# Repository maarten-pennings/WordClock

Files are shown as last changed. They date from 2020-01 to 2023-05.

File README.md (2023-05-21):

# WordClock
A clock that tells time in plain text. In Dutch, e.g. "TIEN OVER HALF TWAALF".

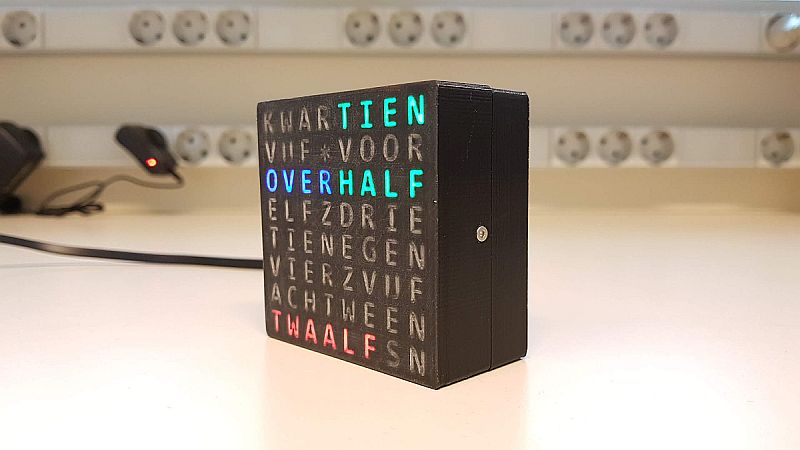
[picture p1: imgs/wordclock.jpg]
WordClock


Commercial [products](https://qlocktwo.com/) exist, but I'm making my own.

Here is a demo [video](https://youtu.be/8YMuuo80cz0) of all animations,
or look at just
[none](https://youtu.be/OCgUQ6qWnN4),
[wipe](https://youtu.be/U9yd8xaslh4),
[dots](https://youtu.be/AXKME2LGA_A),
[pulse](https://youtu.be/F0VIralrmUM), or
[mist](https://youtu.be/u285F07go_c).

There is a [video](https://youtu.be/0UkmPO7tGsg) looking at the mechanics (casing) of the WordClock,
and a [video](https://youtu.be/4AUioVwlsqg) comparing it to a DCF77 clock.

I also made a [white](https://youtu.be/0g2qCgmOJZo) version.

This is the [playlist](https://www.youtube.com/playlist?list=PLrlJSwck1Q0i3ywVSwM-FqwnLM_yhguJa) of all WordClock videos.

## Table of contents

 - [1. Introduction](#1-Introduction) - What is this project about
 - [2. Model 1](#2-Model-1) - My first experiment
 - [3. Model 2](#3-Model-2) - Improved lettering
 - [4. 3D printing](#4-3D-printing) - 3D printed lettering
 - [5. NeoPixel power](#5-NeoPixel-power) - How much power is needed for NeoPixels
 - [6. Model 3](#6-Model-3) - Using the 3D printed lettering
 - [7. Keeping time](#7-Keeping-time) - How to keep time with NTP
 - [8. Timing](#8-Timing) - Disable interrupts disables time keeping
 - [9. Power architecture](#9-Power-architecture) - How to provide power to the NeoPixels
 - [10. Modding the board](#10-Modding-the-board) - Selecting an ESP8266 board
 - [11. Model 4](#11-Model-4) - Assembling the electronics and 3D printed case
 - [12. Model 5](#12-Model-5) - Adding the time keeping software
 - [13. Model 6](#13-Model-6) - End-user application "WordClockFull"
 - [14. User manual](#14-User-manual) - The user manual of "WordClockFull"
 - [15. Replication](#15-Replication) - Making one more
 - [16. Delay](#16-Delay) - Determining the timing between first and last NeoPixel

Notes
 - There are several [Arduino sketches](sketches/README.md) used during development.
 - There are some [Python scripts](scripts) used during development.
 - There are [STL](stls) files for 3D printing.

## 1. Introduction

I had seen WordClocks before, e.g. [here](https://www.instructables.com/id/My-Arduino-WordClock/).
However, doing the mechanics for 100 LEDs, isolating them (light bleed), wiring them - too much work.

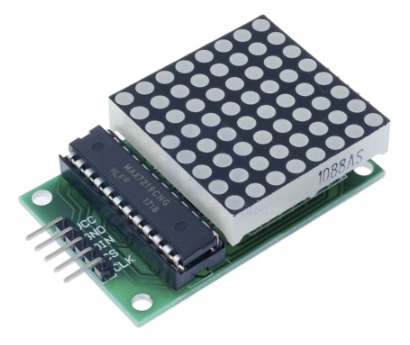
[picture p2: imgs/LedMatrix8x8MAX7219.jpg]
8x8 LED matrix


Then I stumbled on a simpler [version](http://www.espruino.com/Tiny+Word+Clock).
It uses an 8×8 LED matrix (and a MAX7219 controller), so very little mechanics to do.
The downside is that 8×8 LEDs means we are very restricted on the _lettering_: 
which letters (words) are placed where and how.

## 2. Model 1

I want a Dutch word clock.
I do not like vertical text. Is it possible to fit all this on 8×8?

For the hours, we need words `een` (1) to `twaalf` (12). That is 48 characters - note we are writing `vĳf`, not `vijf`.
This means that we can not have words for all 60 minutes. Let's try to go for multiples of 5 only.
In Dutch this means `vĳf` (`over`), `tien` (over), `kwart` (over), tien (`voor` half), vĳf (voor half), `half`, vĳf (`over` half), etc.
That is 24 characters.

Oops, 24+48 is 72, and we only have 64. 
But we can save a bit, for example, for `tien` and `negen`, we only need `tienegen`.

For my first prototype, I made a graph, coupling first letters to last letters of words. I started with the minutes:

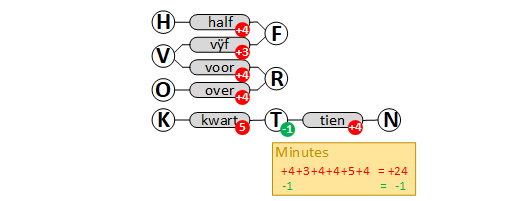
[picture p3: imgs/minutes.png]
Minutes graph


We can only save 1 character, but that doesn't help, we go from 24 to 23. But 24 is 3 rows, and saving one character 
on the last row doesn't help, we can not fit an hour there.

Two solutions are shown below. They fit in three rows.
```
  vĳfkwart     kwartien
  tienvoor     vĳf_voor
  overhalf     overhalf
```

Note that `vĳf`, `tien`, and `kwart` need to come before `over` and `voor`, and only then we can have `half`.
So there is not much room for alternatives.

Let's next look at the hours. They need to come after the minutes.
The complete graph is shown below.

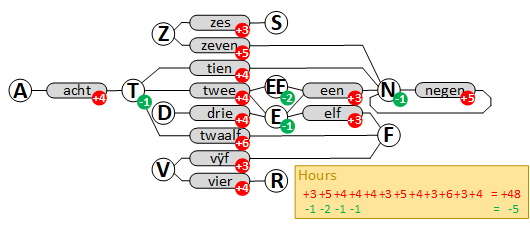
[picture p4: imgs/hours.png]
Hours graph


We have a problem. Full words require 48 characters. We can, at best, save 5, which still requires 43. 
But we only have 40 (5 rows of 8), so we need to get rid of 3 more characters.

I cheated in my first prototype: two paired letters vIEr and twaaLF, and one split word Z-E-S. 
There are also some minor problem: two times a space missing (between `tien` and `voor`, and between `over` and `half`) 
and the word `uur` missing (for every full hour).

This is my first attempt.

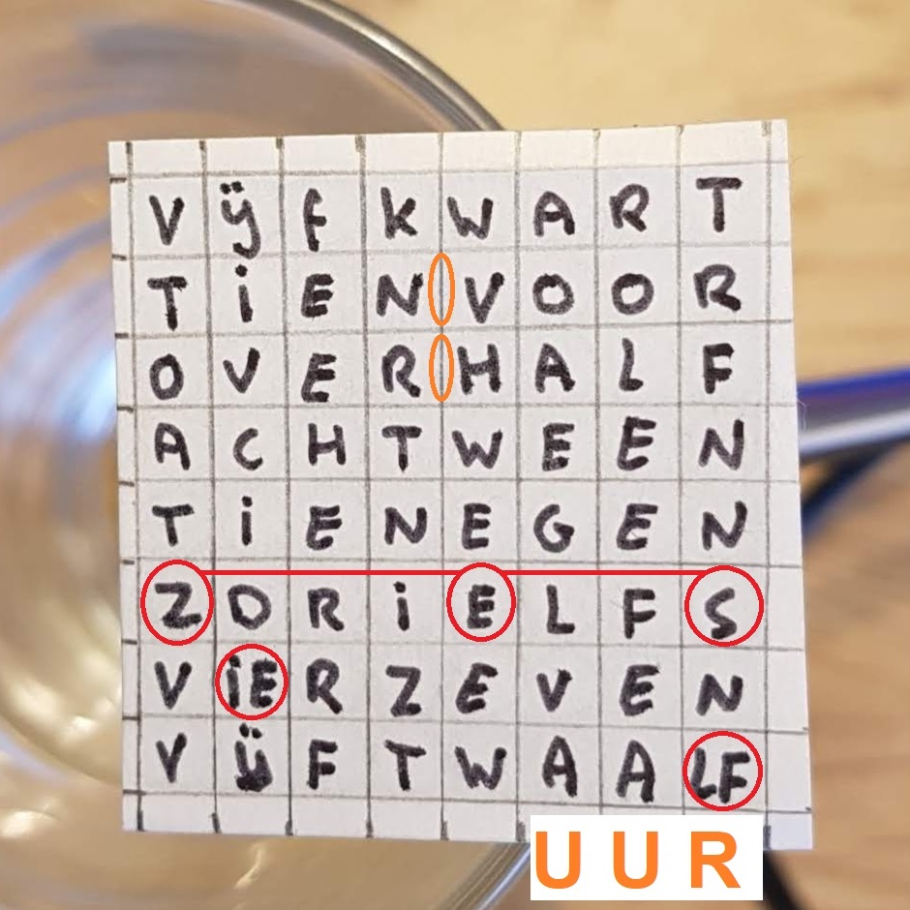
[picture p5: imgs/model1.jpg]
Prototype 1


The first prototype was made with an ESP8266, and an 8×8 LED matrix.
The wiring is straightforward:

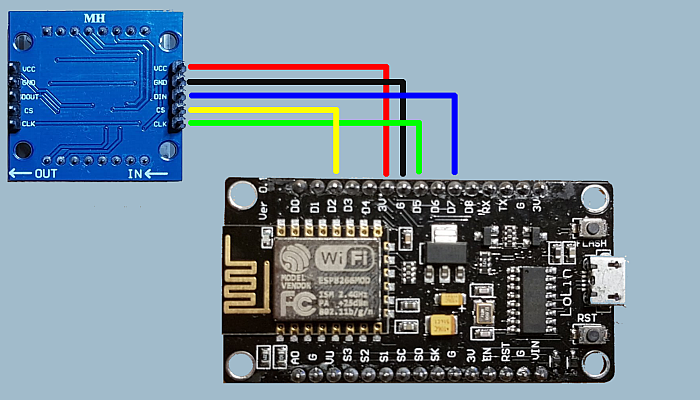
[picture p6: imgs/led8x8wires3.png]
Led 8×8 wiring


I made a [video](https://www.youtube.com/watch?v=YDhCZarNm9g) that runs 
at approximately 600× so that all states appear in a one minute movie.

I also made a [real clock](sketches/WordClockLed) and a
[video](https://youtu.be/wVqeRSxwd_Y) that captures one state change.
This really keeps the time (based on the ESP8266 crystal).
At startup the user can press the FLASH button to set the hour and minute.

## 3. Model 2

Marc relaxed the rules, he allows diagonal words. He wrote a solver algorithm and found the below lettering solution.

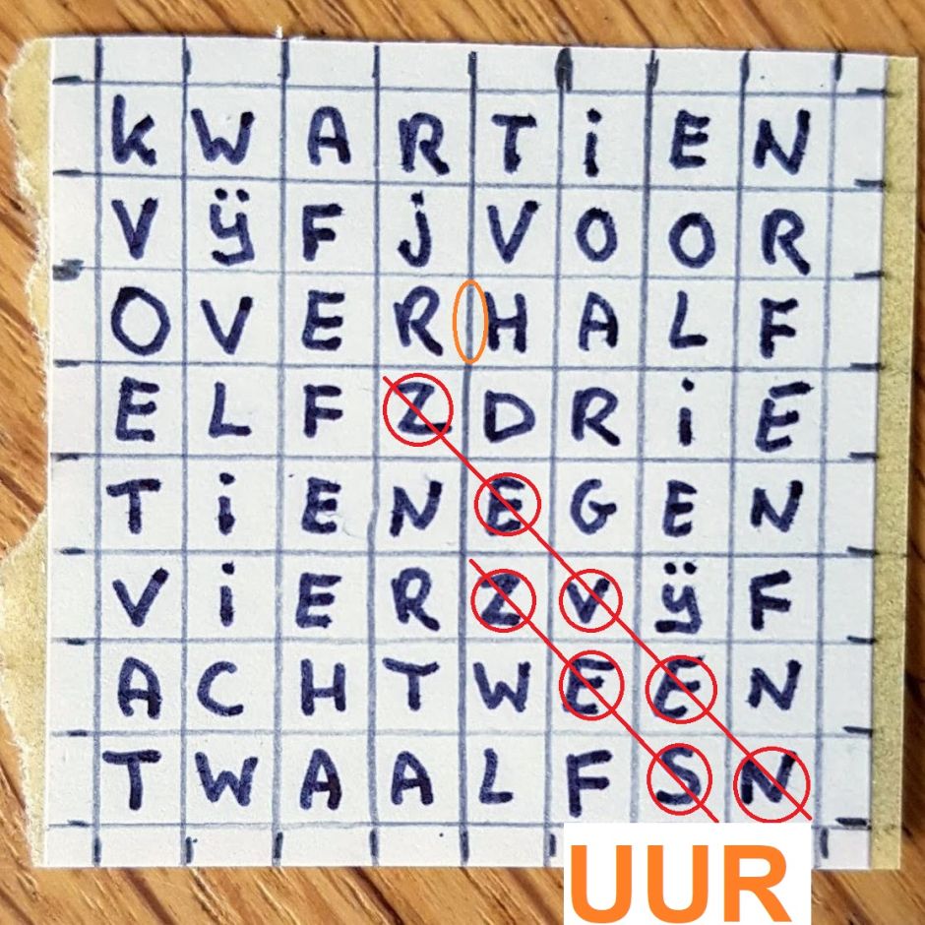
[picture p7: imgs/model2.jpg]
model 2


This eliminates the paired letters and split words. Still a missing space, and still `uur` missing.

My next prototype uses Marc's lettering. It is supported by the same [sketch](sketches/WordClockLed) as the first prototype.

At startup you can not only set hour and minute, but also mode: clock or a fast demo.
Here is the [video](https://www.youtube.com/watch?v=LO9IB6KRluM) of the fast mode.

## 4. 3D printing

The good thing of the [8×8 LED matrix](https://www.aliexpress.com/item/32681183937.html) is that hardly any mechanics are needed. 
The downside of the 8×8 LED matrix, is that the 8×8 matrix is small, in my case 32×32 mm².

However, there are also [8×8 NeoPixel boards](https://www.aliexpress.com/item/32671025605.html).
Twice as big (65×65 mm²), fully assembled and still affordable (~3 euro/dollar).
On top of that: the LEDs are full RGB and only a single wire to control all LEDs.

Note that most new NeoPixel boards use the WS2812B. This is a 4 pin device. 
Its predecessor is known as WS2812 (without the B). This is a 6 pin device.

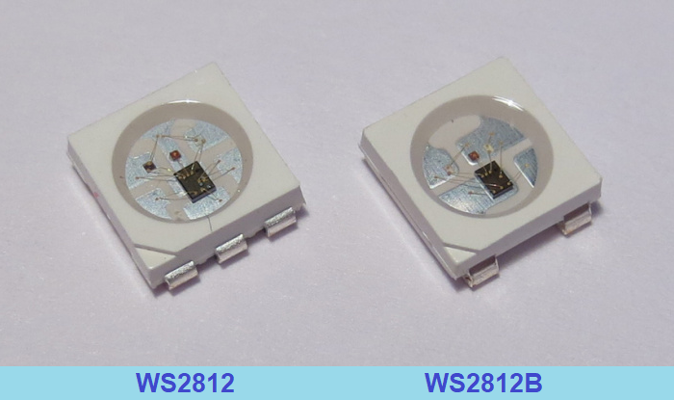
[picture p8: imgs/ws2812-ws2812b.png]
WS2812 and WS2812B


The 4 pin devices are easy to control: 2 pins for power (VCC, GND), 
one pin to clock in the 24 bits RGB values (data-in),
and one pin to clock out RGB data, which allows NeoPixels to be daisy-chained.

The 8×8 NeoPixel matrix is big enough to allow the clock to be 3D printed.
I used a printer with two heads. The first head prints the black encasing, the second head prints a 
transparent diffuser (also _inside_ the letters). This should prevent light bleed.

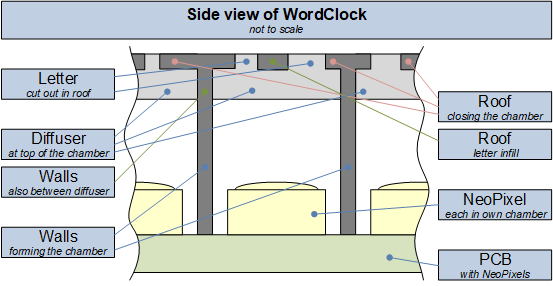
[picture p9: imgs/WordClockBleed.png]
Side view


The [design](stls) is made in Fusion 360.
I was quite pleased with the result. The print resolution is sufficient to print the letters. 
And the transparency is enough to see through.

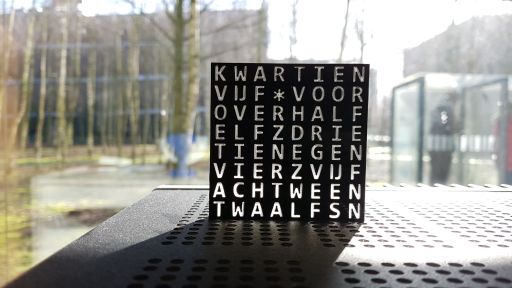
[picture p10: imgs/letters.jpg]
Letters with back light


I did not yet receive the NeoPixel matrix from AliExpress, so I had to guess where to leave a notch for the resistors.

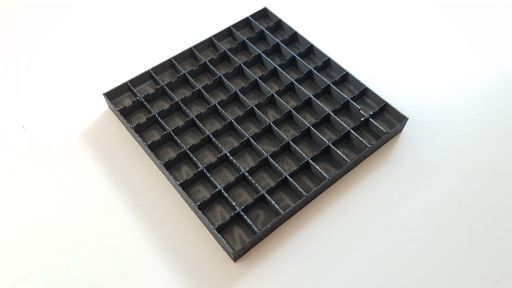
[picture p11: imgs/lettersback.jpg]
Back side of the letters


## 5. NeoPixel power

One thing that worries me about the NeoPixels is power usage. I tasked myself with measuring it.

It is helpful to understand the inner workings of a NeoPixels.
It contains a controller and three LEDs.

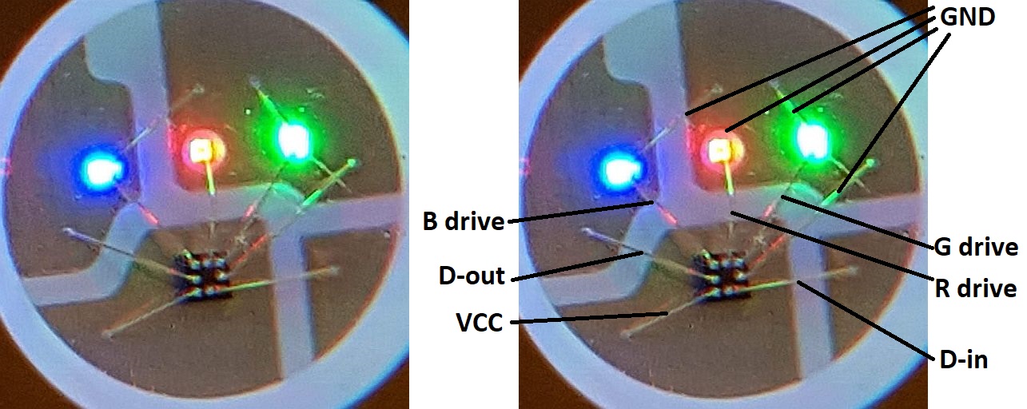
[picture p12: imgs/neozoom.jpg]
Inside NeoPixel


Note that the LEDs are "glued" on the 4 "copper" leads.
The controller is powered (two bond wires coming from two leads), and it drives the three LEDs 
(three bond wires going from controller to the LEDs, and the LEDS then wired to GND).
Finally the controller is bond wired to the data-in and data-out leads.
Note that my annotation is guessed, VCC and GND could be swapped, so could data-in and data-out.

I did have a 4×4 NeoPixel board, and I investigated the power usage on that board.
I measured the current when 1 NeoPixel is red (0xFF0000). I measured also for 2, 3, ... 16 NeoPixels.
I measured the current when 1 NeoPixel is red but dimmed a bit (0xBF0000), and also for 2, 3, ... 16 NeoPixels.
I measured the red at half brightness (0x7F0000) and at quarter brightness (0x3F0000), for 1 to 16 NeoPixels.
All these experiments use just the red LED in the NeoPixel, so for the next two experiments I used the other
two LEDs in the NeoPixels: green (0x00FF00) and blue (0x0000FF) for 1 to 16 NeoPixels.
Finally I measured when more than 1 LED is on: purple (0xFF00FF) and white (0xFFFFFF).

All in all, 8 experiments, each with 1 to 16 NeoPixels.
The [script](sketches/NeoPixelAmps) was short, but doing all the measurements took quite some time.
I manually logged all [results](sketches/NeoPixelAmps/NeoStats.txt), and then tabulated them in Excel:

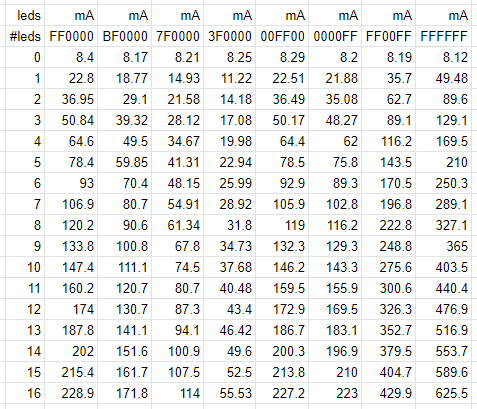
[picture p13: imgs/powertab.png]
Power usage table


Here is the usage graphed:

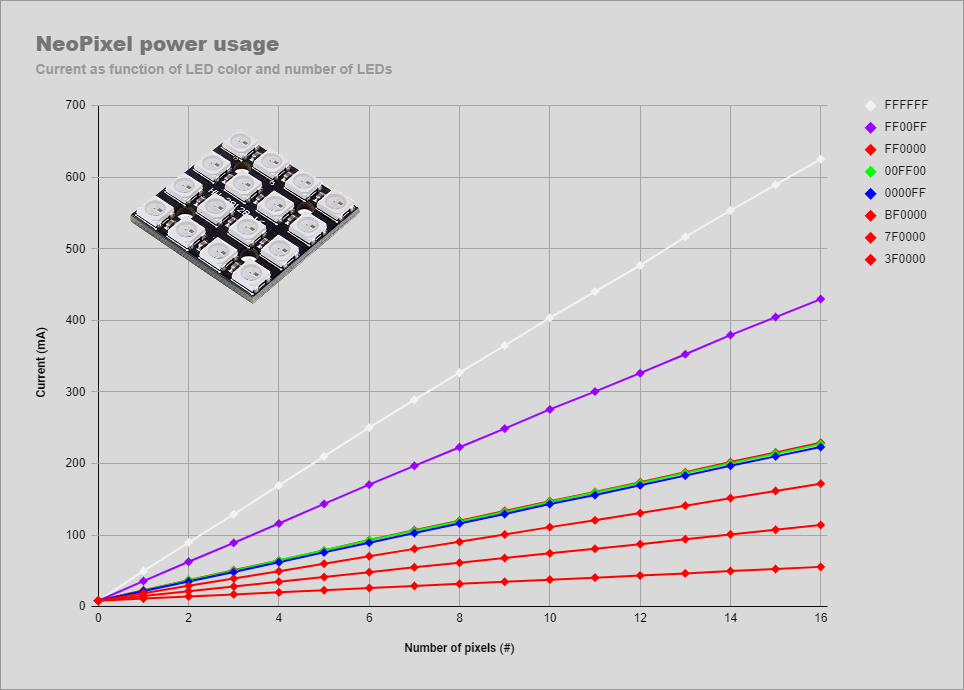
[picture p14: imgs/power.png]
Power usage graph


Conclusions: 
 - There is a off current of 8 mA (0.5mA per NeoPixel), probably due to the controllers in the 16 NeoPixels
 - A NeoPixel LED consumes 12.9mA when fully powered (0xFF).
 - The power usage of a NeoPixel LED is linear in the control value (00..FF).
 - The power usage of a NeoPixel sequence is linear in the number of NeoPixels switched on.
 - A 4×4 at full white (0xFFFFFF) thus consumes 16x3x12.9 + 16x0.5= 627 mA
 - A 8×8 at full white will likely consume 64×3×12.9 + 64×0.5 = 2509 mA or 2.5 A.

For the final product, the power usage can be estimated as follows..
Let's assume the display shows 17 characters (TIEN VOOR HALF NEGEN), 
each in a primary color (red, green, blue), and each at 20%.
This comes close to the default configuration.
Recall that a 100% / LED consumes 13mA, the 64 NeoPixels have standby current of 32mA and the ESP8266 NodeMCU
uses 80mA. This results in an operating current of 20% × 13 × 17 + 32 + 80 ≈ 156 mA.
This is well within standard USB specification, which says 500mA max.

The mist animation switches nearly all pixels on, to gray.
The default mist color is 0x222222, which means 0x22 or 34 per color channel. This is 34/255 or 13% of full power.
During mist, the pixels vary from 13% to 0%,so let's estimate 7% average for 50 pixels for all three LEDs (gray).
This means the power estimate is 7% × 13 × 50 × 3 + 32 + 80 ≈ 250 mA.
Still half of the max USB spec (500mA).

This figures match quite well with actuals. We measure 148 where we estimated 156, and we measure 247 where we estimated 250.

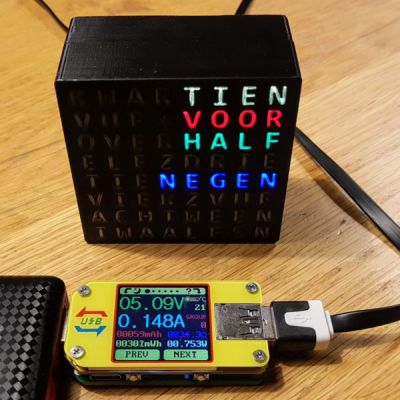
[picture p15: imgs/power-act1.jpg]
Time
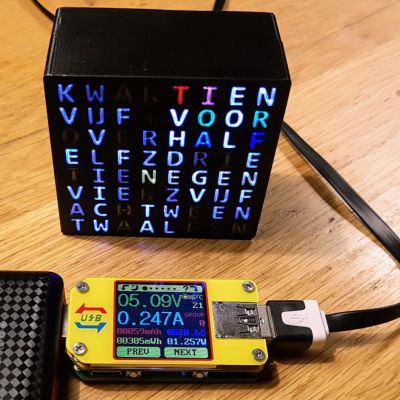
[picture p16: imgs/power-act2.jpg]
Animation
  

## 6. Model 3

Finally, I received the NeoPixels matrix.

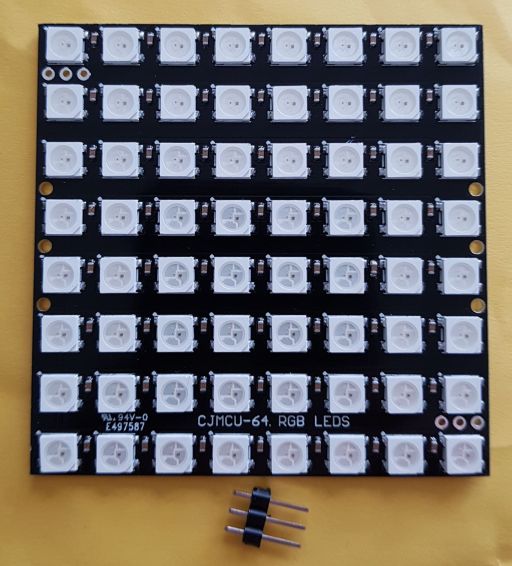
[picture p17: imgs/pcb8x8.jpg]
NeoPixel front


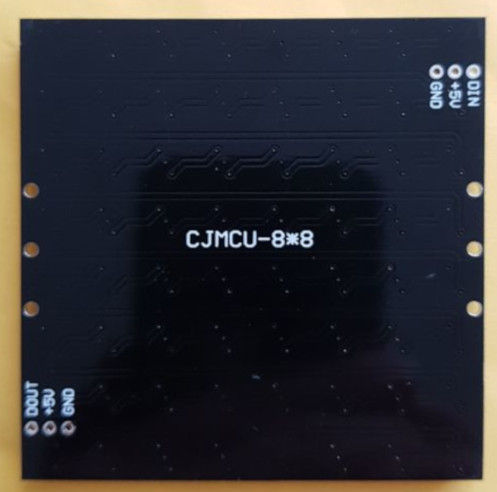
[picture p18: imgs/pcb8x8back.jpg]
NeoPixel back


Unfortunately, the resistors are not centered.
Also the matrix is not equal in horizontal and vertical direction: 
in horizontal direction the spacing is ~8.1mm and in vertical direction the spacing is ~8.3mm.
Result: the 3D print does not fit well.
I needed to make a new [3D model](stls).

See below for the wiring; the resistor is 470 Ω, the capacitor 1000 µF 
(see [Adafruit](https://learn.adafruit.com/adafruit-neopixel-uberguide/basic-connections)).
Note: The Neopixels run at 5V0, and the required signal level is at 70%, or 5V0 × 70% = 3V5.
Since the ESP8266 runs on 3V3, we are actually below spec.

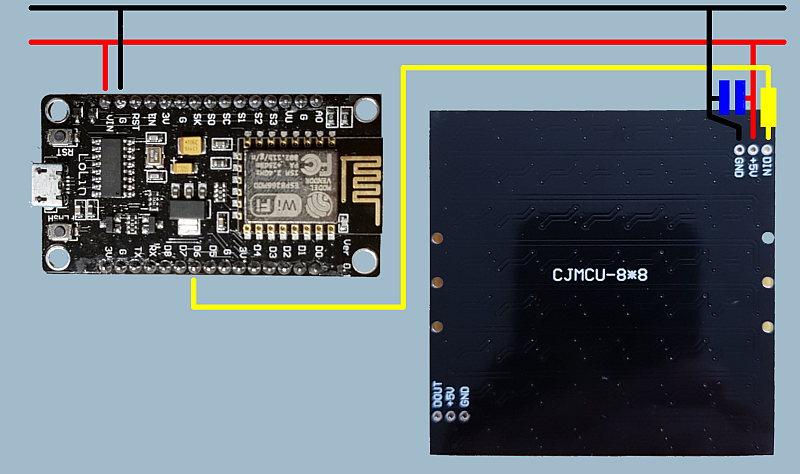
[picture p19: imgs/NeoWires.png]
NeoPixel wiring


I adapted the [software](sketches/WordClockNeo) and did a try-out. 

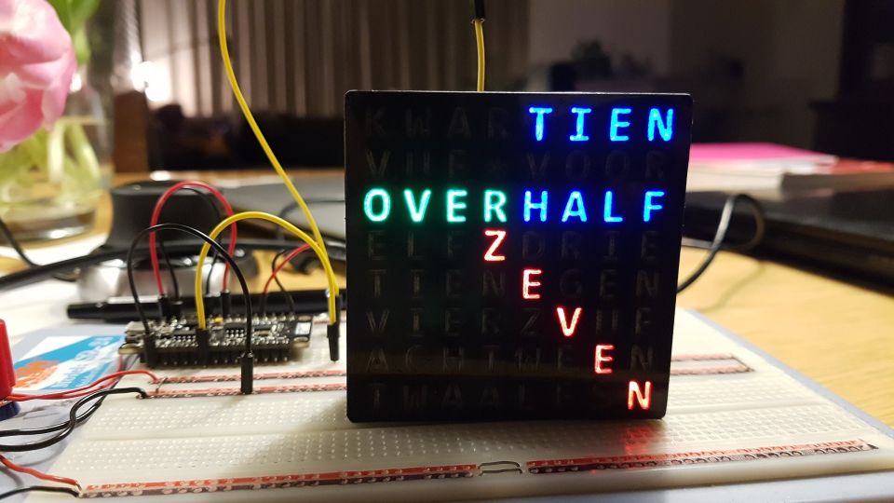
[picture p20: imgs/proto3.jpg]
Running NeoPixel


I made a [video](https://youtu.be/TlJQuVb-GIA) of it.

## 7. Keeping time

Now that the NeoPixel solution with 3D printed enclosure seems to work, we needed to tackle the next biggest problem.
Keeping track of time. There are several solutions:

 - Hand set the time, and use the built-in CPU crystal  
   Plus: No extra components needed.  
   Minus: Needs hand setting. Does not know about daylight saving time ("DST").
 - Use a [DS1307](https://www.aliexpress.com/item/32827794525.html) or [DS1302](https://www.aliexpress.com/item/32728498431.html) time tracking chip  
   Plus: Keeps time, even when not mains powered (small battery).  
   Minus: Needs hand setting once and does not know about daylight saving time.   
 - Use time stamp from webservers (e.g. http HEAD of google.nl)  
   Plus: No extra components needed (assuming ESP8266), no hand setting needed.  
   Minus: Web servers publish UTC, not local time. So adaptations for time zone and DST needed.
 - Use NTP servers  
   Plus: Servers are made for it. No extra components needed (assuming ESP8266), no hand setting needed.  
   Minus: NTP servers publish UTC, so again, adaptations for time zone and DST are needed.

When I found out the ESP8266 `<time.h>` actually includes NTP
and that the implementation has a single string parameter to configure time zone as well as DST,
I decided to use the last solution.

It basically boils down to telling `<time.h>` which NTP servers to use and what the timezone and DST configuration is.
Actually up to three servers can be passed. The timezone and DST configuration is passed as the first parameter:

```
  configTime(TZ, SVR1, SVR2, SVR3);
```

The first parameter (`TZ`) is a quite compact string. As an example, let's examine the string for Amsterdam.

```
  #define TZ "CET-1CEST,M3.5.0,M10.5.0/3" // Amsterdam
```

The first part of this string, before the comma, defines the (standard) timezone and the daylight saving timezone.
In the example, the (standard) timezone is known as `CET`, and you need to subtract 1 (`-1`) to get to UTC.
The daylight saving timezone is known as `CEST`, and since it is not explicitly included, 
it defaults to one (`1`) on top of the standard time.

After the comma we find the start moment of the daylight saving period: it starts at month `3` (March), week `5`, on Sunday (day `0`).
The `M` tells that the month, week, day notation with `.` is used.
After the next comma, we find when daylight saving stops: at month `10` (October), week `5`, day `0` (Sunday).
Also here in `M` and `.` notation.
The start is at 02:00:00 (default), the stop is explicit at 03:00:00 (`/3`).

See the [source](sketches/TimeKeeping) for more 
[details](https://github.com/maarten-pennings/WordClock/blob/master/sketches/TimeKeeping/TimeKeeping.ino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,end) 
on this string. The easiest way to play with this yourself is to change the string so that the timezone change (to or from DST)
is a couple of minutes from now. For this it is good to know that you can enter `M3.5.0/17:34`.

Also, the ESP8266 comes with standard time zones, see `C:\Users\maarten\AppData\Local\Arduino15\packages\esp8266\hardware\esp8266\3.0.2\cores\esp8266\TZ.h`.

Here is the output of the script
```
time-keeping - NTP with TZ and DST
Not yet synced - 1970-01-01 09:00:00 (dst=0)
Not yet synced - 1970-01-01 09:00:01 (dst=0)
Not yet synced - 1970-01-01 09:00:02 (dst=0)
Not yet synced - 1970-01-01 09:00:03 (dst=0)
SET
2020-02-17 12:43:48 (dst=0)
2020-02-17 12:43:49 (dst=0)
2020-02-17 12:43:50 (dst=0)
2020-02-17 12:43:51 (dst=0)
2020-02-17 12:43:52 (dst=0)
2020-02-17 12:43:53 (dst=0)
2020-02-17 12:43:54 (dst=0)
2020-02-17 12:43:55 (dst=0)
2020-02-17 12:43:56 (dst=0)
2020-02-17 12:43:57 (dst=0)
2020-02-17 12:43:58 (dst=0)
2020-02-17 12:43:59 (dst=0)
DEMO >>> WiFi off: time continues
2020-02-17 12:44:00 (dst=0)
2020-02-17 12:44:01 (dst=0)
2020-02-17 12:44:02 (dst=0)
2020-02-17 12:44:03 (dst=0)
2020-02-17 12:44:04 (dst=0)
DEMO >>> Clock reset: time continues from reset val
SET
Not yet synced - 2000-11-22 11:22:34 (dst=0)
Not yet synced - 2000-11-22 11:22:35 (dst=0)
Not yet synced - 2000-11-22 11:22:36 (dst=0)
Not yet synced - 2000-11-22 11:22:37 (dst=0)
Not yet synced - 2000-11-22 11:22:38 (dst=0)
DEMO >>> WiFi on: time syncs again
Not yet synced - 2000-11-22 11:22:39 (dst=0)
Not yet synced - 2000-11-22 11:22:40 (dst=0)
Not yet synced - 2000-11-22 11:22:41 (dst=0)
SET
2020-02-17 12:44:14 (dst=0)
2020-02-17 12:44:15 (dst=0)
2020-02-17 12:44:16 (dst=0)
2020-02-17 12:44:17 (dst=0)
... many lines deleted
2020-02-17 13:44:10 (dst=0)
2020-02-17 13:44:11 (dst=0)
2020-02-17 13:44:12 (dst=0)
2020-02-17 13:44:13 (dst=0)
SET
2020-02-17 13:44:15 (dst=0)
```

 - At first, the time is not yet set, so we get "random" value (probably the date/time corresponding with value 0).
   My sketch uses the heuristic that any time before 2020 means 'not synced'.
   Note that the time keeping (stepping a second every second) happens, even though the time has not yet been SET.
 - It takes 5 seconds before we receive the first message from one of the NTP servers. 
 - At 2020-02-17 12:43:48, an NTP message arrives (see the SET). The time is known.
   Since 17 Feb is before DST start "month 3 (March), week 5, on Sunday (day 0)", daylight saving is indeed off `(dst=0)`.
 - At around 12:44:00 the script executes a test: it switches off WiFi.
   The time is maintained by the CPU (probably: crystal, timer, interrupt).
   So even without network, time is kept.
 - At 12:44:05 a second test kicks in.
   The local clock is hand written to 2000-11-22 11:22:33.
   Note the SET popping up, this time caused by hand-setting, not an NTP message.
   Since there is no WiFi, the hand-set time is maintained.
 - At 12:44:10 WiFi is switched on (step 3 of the test). 
   Since there is not an immediate NTP message, the old hand-set time is still maintained.
 - At 2020-02-17 12:44:14 an NTP message is received.
   The clock is back to real time, and locally maintained.
 - Note that one hour later (2020-02-17 13:44:14) the system (asks for and) receives the next NTP message.
   See the SET. The local clock is synced.

All in all, we have a firm basis for having an accurate time.

## 8. Timing

NeoPixels are controlled via a single serial line. One NeoPixel has three LEDs (red, green and blue), whose brightness
can be controlled from 0..255. So to configure one NeoPixel, it needs to be send 3×8 bits. Since there is no clock, 
biphase encoding is used: every bit uses a low and a high signal, so every bit has an edge (actually two). The datasheet 
[WS2812B](https://cdn-shop.adafruit.com/datasheets/WS2812B.pdf) or [WS2812](https://cdn-shop.adafruit.com/datasheets/WS2812.pdf)
shows this picture of biphase encoding:

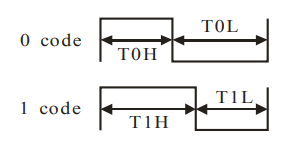
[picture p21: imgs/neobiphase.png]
biphase encoding


I did an experiment where I configured one NeoPixel, to have color `0x81c1e1` (that is red 0x81, green 0xc1, and blue 0xe1). 
I captured the clock signal on my logic analyser.

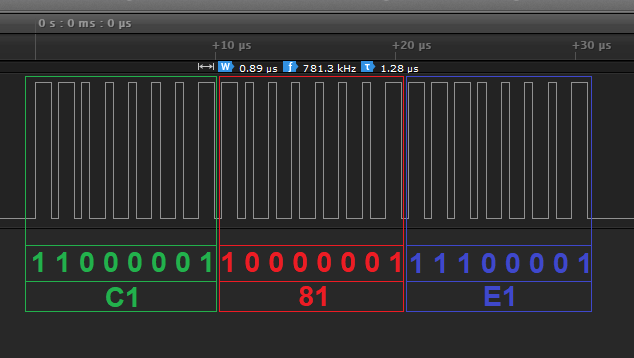
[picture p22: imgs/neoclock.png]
Clock captured


We notice the following

 - The bit clock is ~781kHz, which is close to the 800kHz from the documentation.
 - Note that the measured T1H is 0.89 µs, seems out of spec. It should be 0.7µs ± 150ns, that is 550ns..850ns, so 890 is too long.
 - The protocol is simple: the 3×8 bits are send, no overhead bits.
 - One NeoPixel thus takes 24/800k = 30µs to configure.
 - Pixel timing is confirmed in the capture: the whole transmission takes just over 30µs.
 - The bits are send MSB first, but in an unconventional order: GRB.
 - The datasheet [WS2812B](https://cdn-shop.adafruit.com/datasheets/WS2812B.pdf) or
   [WS2812](https://cdn-shop.adafruit.com/datasheets/WS2812.pdf) confirms the order
   NeoPixel color order.

Next experiment is to send an RGB value to all 64 NeoPixels. This is my capture.

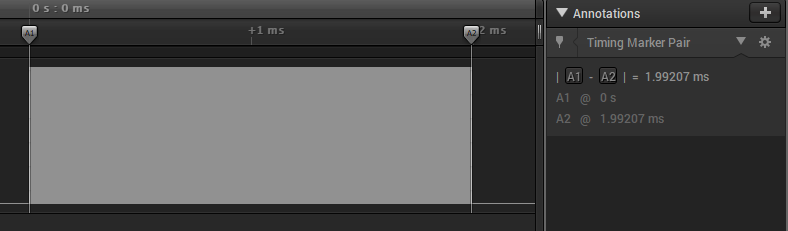
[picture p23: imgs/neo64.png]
Timing 64 NeoPixels


On this zoom level we can no longer see the indvidual bits. But sending 24 bits to each of the 64 neoPixels is expected to take
30µ × 64 = 1.92 ms. The capture confirms this: 1.99 ms.

Why is this relevant?
On the ESP8266, this string is bit-banged: all bits are generated by software. 
That is feasible: each bit is ~1µs, and the ESP8266 runs on 80MHz (say 80 instructions per µs).
However, it should not service an interrupt half-way.
For this reason, the NeoPixel library seems to disable interrupts.
This means that during an update of the 64 NeoPixel string, interrupts are disabled for 2ms.
During this 2ms, all interrupts are disabled, so `millis()` might miss ticks.

How realistic is this problem?
I found this [topic](https://forums.adafruit.com/viewtopic.php?f=47&t=42720#p212310).
It states that there is a timer interrupt every 1 ms, so if the disable-interrupt-time is 2ms
we miss interrupts and thus have clock drift. And 64 NeoPixels need about 2ms without interrupts.
So again. Are we at risk?

It seems that the above discussion is for plain Arduinos; the situation for the ESP8266 is a bit different.
It has a function `micros_overflow_tick()` which seems to be called periodically.
It seems to _monitor_ a hardware timer `system_get_time()` for overflows.
If there is an overflow, it increments a variable `micros_overflow_count`.
Check the code on your PC, or 
[here](https://github.com/esp8266/Arduino/blob/d990ff9547cf1bea7f91f3e3ad2c2eb8066c698f/cores/esp8266/core_esp8266_wiring.cpp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).

The function `millis()` uses `system_get_time()` and `micros_overflow_count` to
[compute](https://github.com/esp8266/Arduino/blob/d990ff9547cf1bea7f91f3e3ad2c2eb8066c698f/cores/esp8266/core_esp8266_wiring.cpp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)
the elapsed milliseconds.

So, can the ESP8266 also lose time?
For that it needs to lose a tick on `micros_overflow_count`.
It loses that when `system_get_time()` overflows without `micros_overflow_tick()` having been called.
It seems that `system_get_time()` counts micro seconds and it has a range of 32 bits.
So `system_get_time()` overflows every 2³² µs or 1.2 hour.
I expect the monitor function `micros_overflow_tick()` to be called much more frequently (say every second).
So losing one interrupt causes no harm at all, there would be 3599 to detect the overflow.

My guess is that on ESP8266 we do not suffer from losing time.
Marc did an experiment, continuously flashing NeoPixels, and indeed found no time drift.

## 9. Power architecture

We are going to use an ESP8266 for the WordClock. ESP8266s are easily and cheaply available, and they have WiFi.
That allows us to use NTP (time syncing) which makes them well suited for maintaining time for our clock.

The ESP8266 runs on 3V3, but typically comes on boards that are powerd via USB (and thus 5V).
These boards have a voltage regulator (LDO) that converts 5V to 3V3. The boards also have a VIN that 
connects to the regulator. This allows us to use an external power supply (4.3V-12V) instead of 
power over USB.

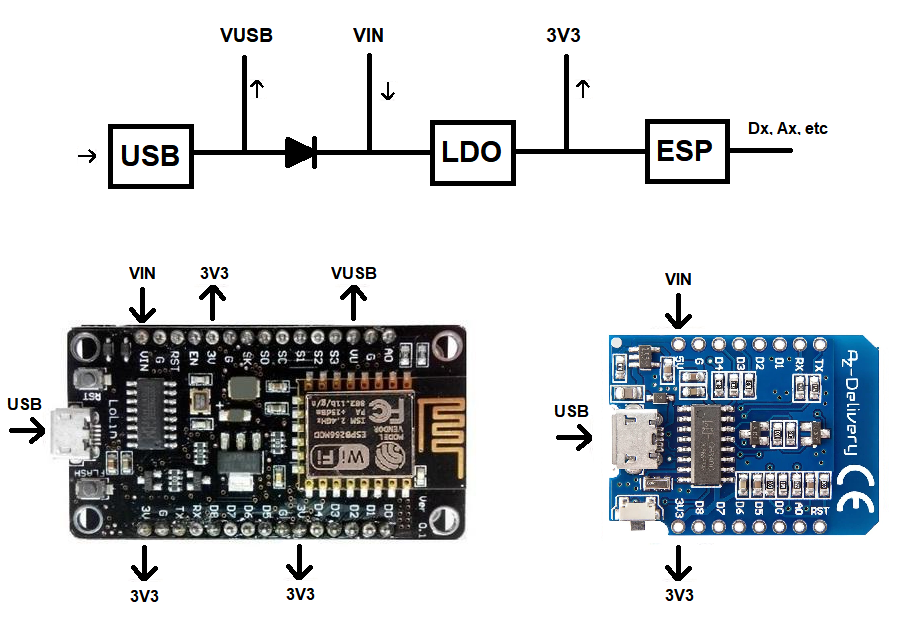
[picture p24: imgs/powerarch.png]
Power architecture


Note that there is a diode between the USB port and VIN. 
If you would externally power the NodeMCU board via VIN (say 9V), and you would also have connected the
USB port to a PC (e.g. for debugging using the Serial port) the external 9V would also be on the PCs USB port, 
possibly damaging it. The diode protects your PC's USB port against over-voltage.

There is an extra effect: the diode has a voltage drop. Typically, a Schottky diode is used, which has 
a voltage drop of only 0.3V. So if you plug in USB (5V), the voltage regulator has 4V7 as input, which is still
enough to have 3V3 out. The side effect is that VIN will be at 4V7.

The NeoPixels need 5V. It would be easiest to tab that from the USB port. Some boards do have a pin for that.
I call it VUSB in the diagram above. However not all (big) boards do have a VUSB pin, and the smaller boards 
typically never have one. 

We could use VIN as _output_ instead of _input_, and power the NeoPixels with VIN. 
This means the NeoPixels run on 4V7, which is acceptable.
That level is actually interesting, because the NeoPixel _data_ pin (DIN) requires at least 70% of VDD.
And that would now be 70% × 4V7 = 3V29, which is below the signaling level of the ESP8266, which runs on 3V3.

However, before we get enthusiastic about this setup, there is one major drawback.
The whole NeoPixel chain would draw current through the diode. The diode is typically limited to 250mA.
That does not match well with the ([above](#neopixel-power)) computed maximum current of 2500mA
(the power the tiny diode would need to dissipate would be 0.3V × 2.5A = 0.7W).  

The bigger boards with VUSB pins are too big for our 3D printed case. So I propose to use
a small board (e.g. [Wemos D1 mini](https://www.aliexpress.com/item/32944522985.html)), remove the diode,
and replace it with a wire. In this way, the VIN is actually converted into a VUSB, and we can
use that pin to power the NeoPixels

Of course we lose the protection, but in our case, the VIN port will wire to the NeoPixels, 
and will not be used as input anymore.

## 10. Modding the board

The Wemos D1 mini takes up half the width/height of the 3D printed case. So we have some room 
for other components. But the [Wemos mini](https://www.aliexpress.com/item/32944522985.html) 
has several drawbacks:

  - There is no VUSB - which we need to power the NeoPixels
  - There is no (flash) button - which we need to configure the clock
  - There are no mounting hole.

The VUSB problem is solved by replacing the diode with a wire as described in the previous section.
See below a photo strip of my soldering.

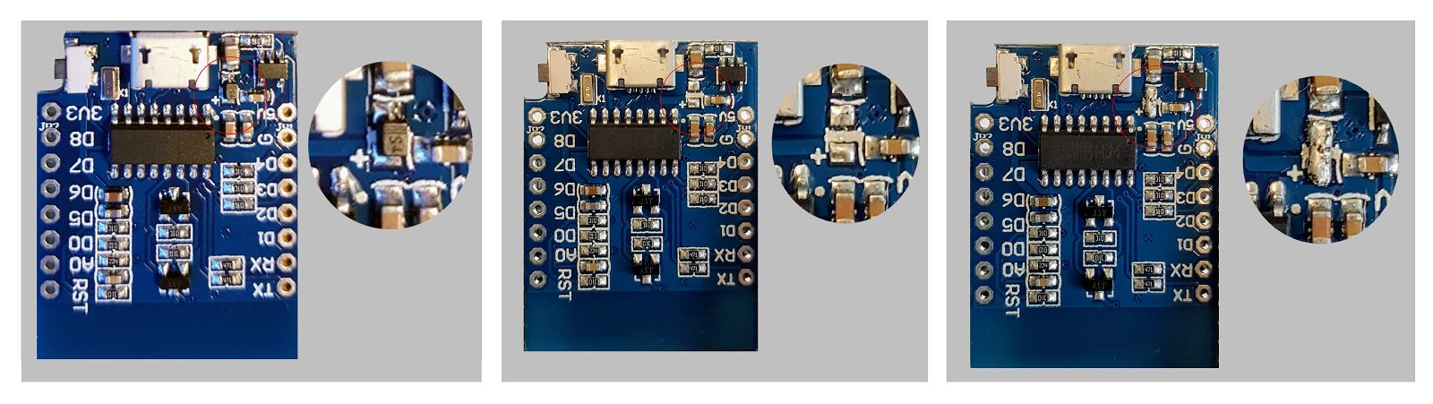
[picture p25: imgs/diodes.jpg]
Replacing the diode with a wire


The flash button is easily added: just solder a button between GND and D3.
I rely on the internal pull up, to have the input high when the button is not pressed.
I added a small board and soldered extra wires, just for mechanical strength;
we are going to push that button, and the mounting holes are in the Wemos board.

Finally I drilled holes next to the ESP8266 module.
See below the end result of my mods.

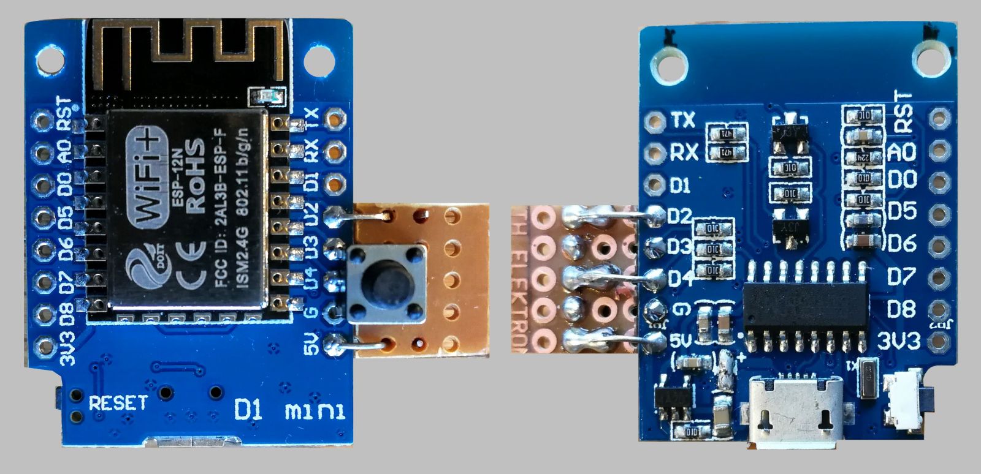
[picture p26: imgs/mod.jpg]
Mods


## 11. Model 4

We need to hook the NeoPixel board to our modded Wemos mini.
I originally did not intend to, but I did, in the end, add a level shifter.
The breadboards suggested it was not necessary, the data sheet said it was.
I played safe, a [level shifter](https://www.aliexpress.com/item/1972789887.html) 
is not that expensive, the bigger problem was putting all the electronics together;
I did not yet feel like making a PCB myself.

This is the schematics I came up with - do note that I replaced the diode with a
wire as described in [modding](#modding-the-board).

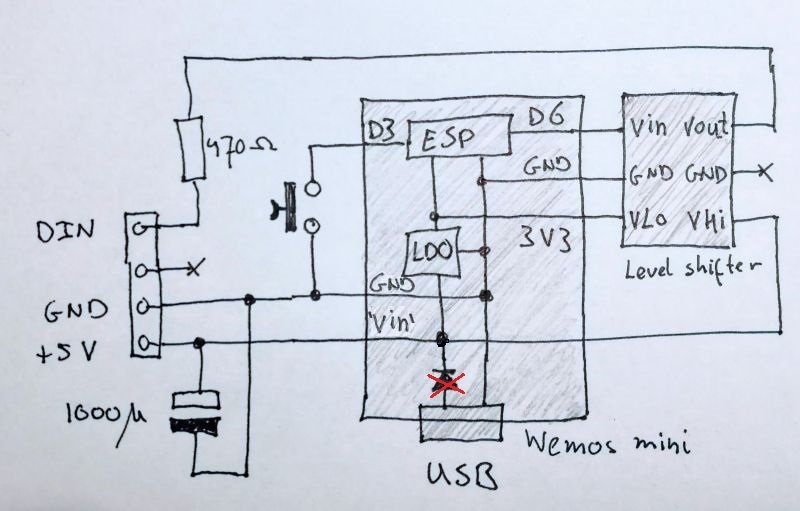
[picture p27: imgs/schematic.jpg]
Schematic


Some notes, added after the project was finished.
 - The breadboard version suggests that the level shifter is not needed at all.
 - With the level shifter, it is working fine. But the claim "playig safe" is naive; the level shifter spec 
   suggests it can _not_ keep up with the signaling speed (800kHz).
 - I have found another [level shifting trick](https://twitter.com/strooom/status/1107028243822141440). 
   Did not try [it](imgs/3v3-5v0-schem.png) out myself, but a quick [measurement](imgs/3v3-5v0-scope.png) seems to validat it.

I added the level shifter in a similar manner as that I added the expansion board for the button.
But this boards has no mechanical stress, so I used only two wires to tie it to the ESP board.

I used the button expansion board (I should have made it bigger) for the other two components:
the resistor to protect the NeoPixels against over-voltage and the capacitor
to mitigate current swings (when the whole NeoPixel board switches on).
See [Adafruit](https://learn.adafruit.com/adafruit-neopixel-uberguide/basic-connections)
for details on these two components.

I added one more "component" on the button expansion board: a four pin header as
the connector towards the NeoPixel board. Pin three is a dummy, so that the connector
can not be inserted up-side-down. The resulting board, the Wemos mini with the two 
expansion boards, is shown in the photo below.

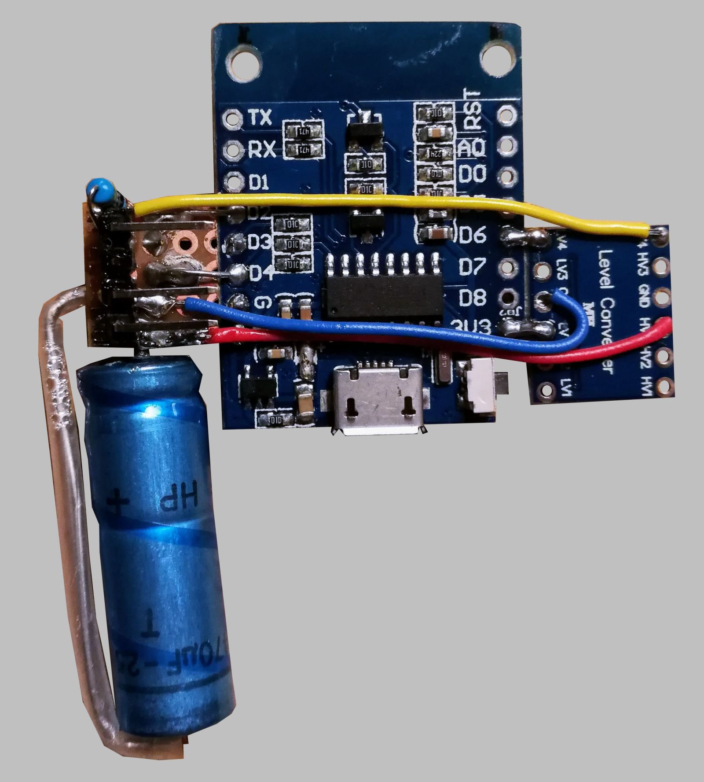
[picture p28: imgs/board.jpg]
The board


Next step is to fit this board in a 3D printed case. Of course, we already had the
[front side](#3d-printing), but I still needed to make the [back side](stls).
In the figure below, we see the main board screwed to the back side (left). On the
right, the NeoPixel board is plugged into the board.

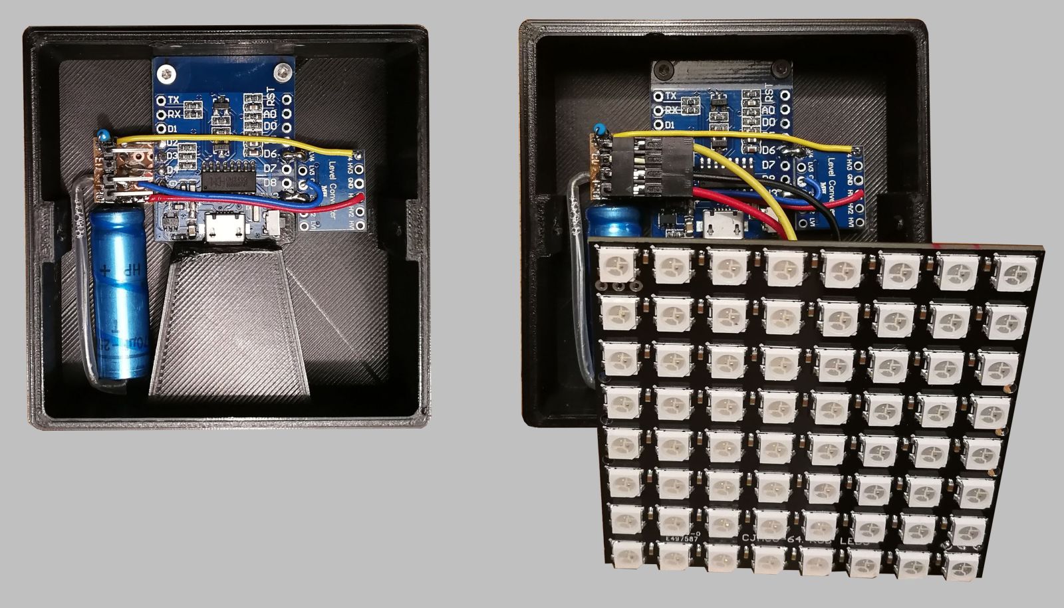
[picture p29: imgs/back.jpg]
PCB in the back side


Below you find a photo showing the back of the device. 
We see (lower center) the recess for the USB plug.
On the top center, we find the light guide towards the LED and the 
hole where the FLASH button surfaces.

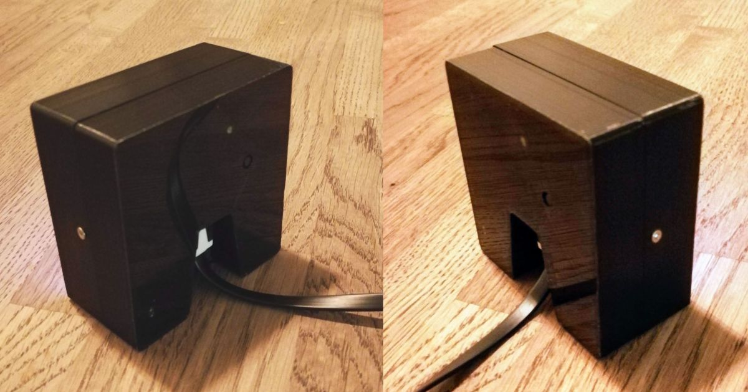
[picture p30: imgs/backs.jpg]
Back sides


To test the electronics, I wrote a small Arduino [sketch](sketches/NeoPixelTest) that switches every LED
in every NeoPixel on. This allows us to see that the electronics works, and whether
all individual LEDs are OK. The photo below shows the fully assembled WordClock running
the self-test.

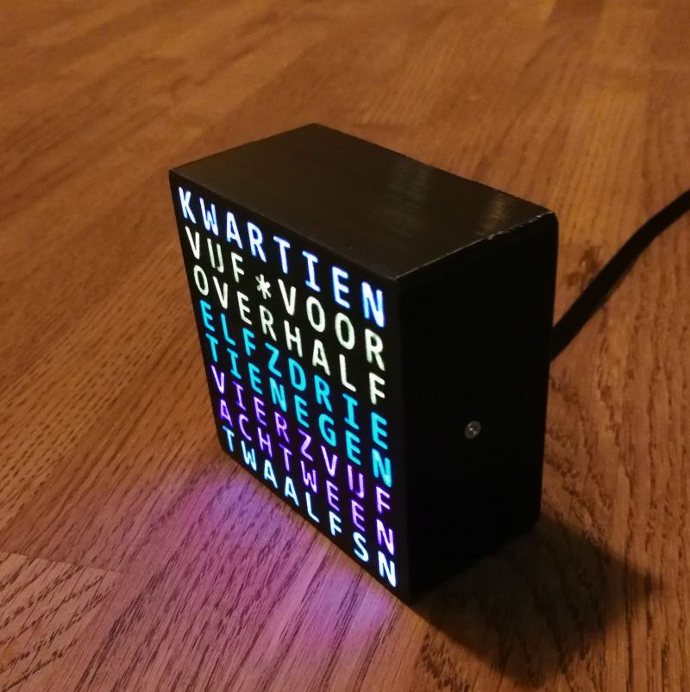
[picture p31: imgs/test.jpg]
Self test


There is also a [video](https://youtu.be/40TDKY0Gjv4) of the device running the self-test.

## 12. Model 5

Mechanics is complete, let's now add the time keeping software.
I decided to make a "simple" version first.
No (dynamic) configuration, no animations.
Find this sketch in [WordClockSimple](sketches/WordClockSimple).

Here is a [video](https://youtu.be/0UkmPO7tGsg) looking at the case - back and front - and the status LED.

Here is a [video](https://youtu.be/4AUioVwlsqg) with the clock running, comparing it to a DCF77 clock.

Some notes on the video
 - The blue LED at the back switches on when the clock is powered and initialized.
 - The blue LED switches off as soon as an NTP sync has occurred, i.e. when the local time is known.
 - The time is then displayed in 5 min resolution.
 - At 10:52:30 (see the DCF77 clock) the WordClock switches from 10:50 (TIEN-VOOR-ELF) to 10:55 (VIJF-VOOR-ELF).

By the way, I made the choice that time is rounded up (instead of floored). 
See the following animation (made in [python](scripts/clock2.py)) for the difference.

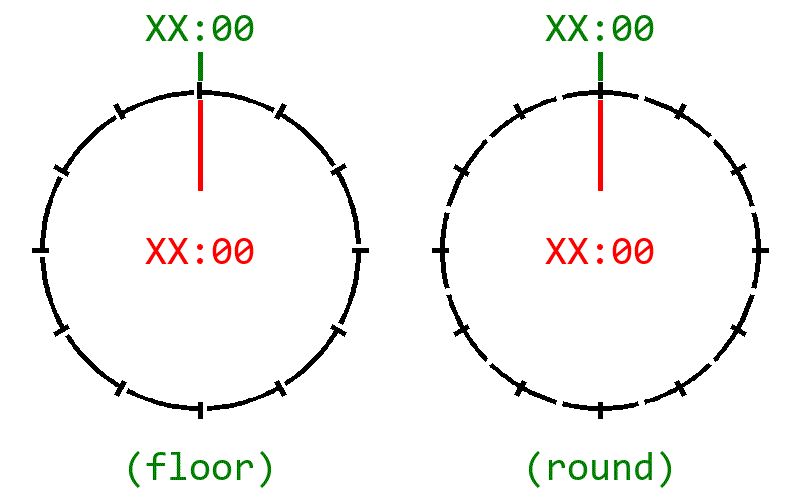
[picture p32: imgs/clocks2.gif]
floor versus round


If you don't like that 10:52:30 is rounded up to 10:55, ..., it's just a `#define` in the code (`CLK_ROUND`).

Find below the output generated over Serial (when there are `...`, I removed lines)

```
main: WorkClockSimple v1

neo : init
led : init
clk : init
wifi: init

clk : 1970-01-01 09:00:00 (dst=0) [no NTP sync yet]
clk : 1970-01-01 09:00:01 (dst=0) [no NTP sync yet]
clk : 1970-01-01 09:00:02 (dst=0) [no NTP sync yet]
clk : 1970-01-01 09:00:03 (dst=0) [no NTP sync yet]
wifi: connected, IP address 192.168.179.102
clk : 2020-02-24 23:23:42 (dst=0) 23:26 vijf-voor-half-twaalf
clk : 2020-02-24 23:23:43 (dst=0) 23:26 
clk : 2020-02-24 23:23:44 (dst=0) 23:26 
clk : 2020-02-24 23:23:45 (dst=0) 23:26 
...
clk : 2020-02-24 23:24:27 (dst=0) 23:26 
clk : 2020-02-24 23:24:28 (dst=0) 23:26 
clk : 2020-02-24 23:24:29 (dst=0) 23:26 
clk : 2020-02-24 23:24:30 (dst=0) 23:27 vijf-voor-half-twaalf
clk : 2020-02-24 23:24:31 (dst=0) 23:27 
clk : 2020-02-24 23:24:32 (dst=0) 23:27 
clk : 2020-02-24 23:24:33 (dst=0) 23:27 
...
clk : 2020-02-24 23:25:27 (dst=0) 23:27 
clk : 2020-02-24 23:25:28 (dst=0) 23:27 
clk : 2020-02-24 23:25:29 (dst=0) 23:27 
clk : 2020-02-24 23:25:30 (dst=0) 23:28 vijf-voor-half-twaalf
clk : 2020-02-24 23:25:31 (dst=0) 23:28 
clk : 2020-02-24 23:25:32 (dst=0) 23:28 
clk : 2020-02-24 23:25:33 (dst=0) 23:28 
...
clk : 2020-02-24 23:26:27 (dst=0) 23:28 
clk : 2020-02-24 23:26:28 (dst=0) 23:28 
clk : 2020-02-24 23:26:29 (dst=0) 23:28 
clk : 2020-02-24 23:26:30 (dst=0) 23:29 vijf-voor-half-twaalf
clk : 2020-02-24 23:26:31 (dst=0) 23:29 
clk : 2020-02-24 23:26:32 (dst=0) 23:29 
clk : 2020-02-24 23:26:33 (dst=0) 23:29 
...
clk : 2020-02-24 23:27:27 (dst=0) 23:29 
clk : 2020-02-24 23:27:28 (dst=0) 23:29 
clk : 2020-02-24 23:27:29 (dst=0) 23:29 
clk : 2020-02-24 23:27:30 (dst=0) 23:30 half-twaalf
clk : 2020-02-24 23:27:31 (dst=0) 23:30 
clk : 2020-02-24 23:27:32 (dst=0) 23:30 
clk : 2020-02-24 23:27:33 (dst=0) 23:30 
```

Notes on the output
 - The first line identifies the program and version.
 - The next 4 lines signal the initialization of the hardware blocks (`setup()`).
 - Then the device is operational (switches to `loop()`).
 - We see that the first couple of seconds, there is no WiFi yet.
 - The WiFi connect occurs, and we see the assigned IP number.
 - Quickly after that, we have the first NTP sync, and the clock knows local time.
 - As output we see `clk : 2020-02-24 23:23:42 (dst=0) 23:26 vijf-voor-half-twaalf`
    - The `clk` identifies the "driver" that prints the message.
    - The `2020-02-24 23:23:42 (dst=0)` is the full (local) date and time locally known,  
      also see we do not yet have daylight saving (`(dst=0)`).
    - The `23:26` is the "rounded-up" time (since we have a resolution of 5 min, 2.5min is added).
    - Each time when hours or minutes change, the display is updated, the text `vijf-voor-half-twaalf` shows which NeoPixels
 - At 23:24:30 there is another minutes change (to `23:27`) and the display is refreshed to `vijf-voor-half-twaalf`.
 - At 23:25:30 there is another minutes change (to `23:28`) and the display is refreshed to `vijf-voor-half-twaalf`.
 - At 23:26:30 there is another minutes change (to `23:29`) and the display is refreshed to `vijf-voor-half-twaalf`.
 - At 23:27:30 there is another minutes change (to `23:30`), so now the display is updated to `half-twaalf`.

## 13. Model 6

The hardware is done, the clock is running.
The final step is to add software features.
The application [WordClockFull](sketches/WordClockFull) is the end-user application.
That directory also contains a complete binary [release](sketches/WordClockFull/release).

WordClockFull contains the following features

 - Color modes  
   The colors used for the hours and minutes can be configured.
   What's more, the color __mode__ can be configured: fixed, cycling or random.
   And the refresh can be every 5 minutes (when the text changes) but also every minute (to have the clock more lively).
   
 - Display animations  
   When the time changes, the display is refreshed. This might mean that the time is drawn in a different color
   (see previous feature: color mode). It is also possible to animate the "old time text"
   to the "new time text". The app has five animations built in: none, wipe, dots, pulse and mist.
   
 - Demo mode  
   To show off the clock (the color modes and display animations) there is now a demo mode.
   By pressing the (flash) button, the clock starts running at 15× speed.
   
 - A configuration interface  
   When powering the WordClock, you have some time to press the (flash) button of the ESP8266.
   If you do that, the actual clock app will not start, instead the configuration app starts.
   This means the ESP8266 starts a WiFi access point (plus DNS and DHCP server), and a web server.
   When you connect to the web server with a laptop or smart phone, you get a web page with configuration parameters.
   Typical parameters are: the SSID and password of your home wifi network, the time zone, 
   the colors for the hours and minutes and the animations to be used.
   When you commit the configuration, the parameters are stored persistently, and the clock app will use them (even after a power cycle).
   
 - A NeoPixel test  
   All LEDs in all NeoPixels are switched on one by one, to test if they are working.

## 14. User manual

The Dutch WordClock running the [WordClockFull](sketches/WordClockFull) firmware has the 
following characteristics.

### Hardware
On the front side, we have 8×8 letters with RGB LEDs behind them.
They form words that tell the time.
This clock is made for the Dutch language.

At the back side there are three user parts.
There is the status LED, a user button and a micro USB connector.

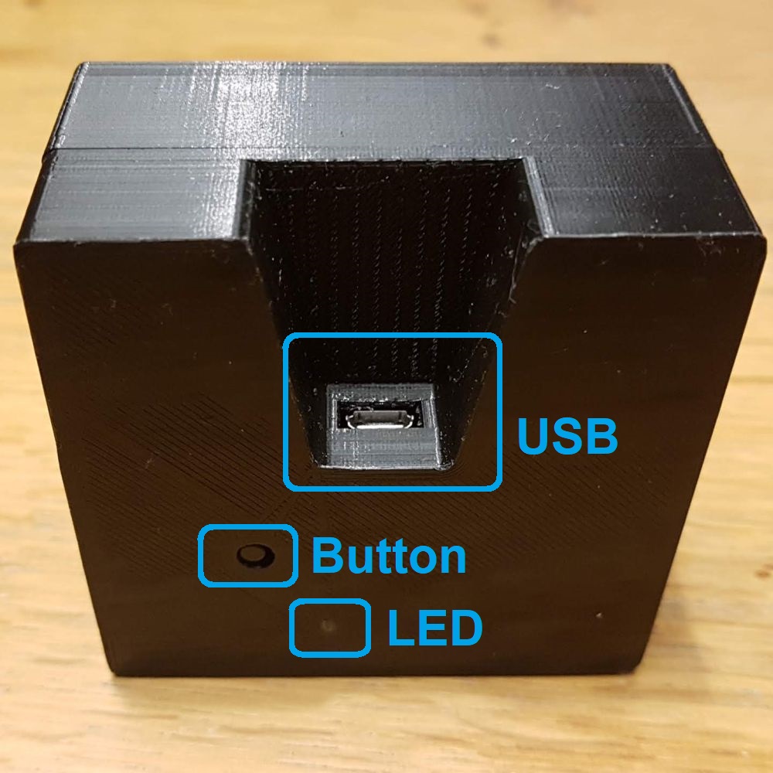
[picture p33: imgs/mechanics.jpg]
User parts


The status LED has multiple functions, described in more detail in the "Normal operation" section below.
It blinks rapidly to signal that the user can press the button to enter configuration mode.
In configuration mode it blinks slowly. In normal mode it is on when searching for WiFi or off when WiFi is connected.

The button also has two functions.
Firstly, at startup, when the status LED is blinking, a press on the button enters configuration mode.
When running the clock app, pressing the button toggles between normal clock mode and demo mode (15× speed).

Finally the USB connector has dual use.
Its main use is power supply to the WordClock.
For normal usage standard 500mA USB is more than sufficient.
If you want all LEDs full bright white, you would need 2500mA.
The power usage can be estimated, see section on [power](#5-NeoPixel-power).

The second use of the USB connector is software development.
When the USB connector is connected to a PC, and a CH340 USB to serial driver is installed, 
and you have a terminal program (115200/8/N/1), the WordClock log can be examined.
You get something like this

```
main: WordClockFull v5                                                          
                                                                                
Cfg: Press button on pin 0 to enter configuration mode                          
main: No configuration requested, started WordClockFull                         
                                                                                
neo : init                                                                      
neo : tested                                                                    
but : init                                                                      
led : init                                                                      
wifi: init: GuestFamPennings MaartenAP dePracht                                 
clk : init: pool.ntp.org europe.pool.ntp.org north-america.pool.ntp.org         
clk : timezones: CET-1CEST,M3.5.0,M10.5.0/3                                     
clk : round: 150 sec                                                            
ltrs: init                                                                      
col : palette: 120000 001200 0C0C00 000018 222222                               
col : max: R12 G12 B18                                                          
col : modes: one cycle mist                                                     
anim: init                                                                      
                                                                                
clk : 1970-01-01 09:00:05 (dst=0) [no NTP sync yet]                             
clk : 1970-01-01 09:00:06 (dst=0) [no NTP sync yet]                             
clk : 1970-01-01 09:00:07 (dst=0) [no NTP sync yet]                             
wifi: connected to GuestFamPennings, IP address 192.168.179.102                 
clk : 1970-01-01 09:00:08 (dst=0) [no NTP sync yet]                             
clk : 2020-03-15 20:31:13 (dst=0) 20:33 (mist) half/0C0C00 negen/120000         
clk : 2020-03-15 20:31:14 (dst=0) 20:33                                         
clk : 2020-03-15 20:31:15 (dst=0) 20:33                                         
anim: mist - stop (2360 ms)                                                     
clk : 2020-03-15 20:31:16 (dst=0) 20:33                                         
clk : 2020-03-15 20:31:18 (dst=0) 20:33                                         
clk : 2020-03-15 20:31:17 (dst=0) 20:33                                         
clk : 2020-03-15 20:31:19 (dst=0) 20:33                                         
clk : 2020-03-15 20:31:20 (dst=0) 20:33                                         
clk : 2020-03-15 20:31:21 (dst=0) 20:33                                         
clk : 2020-03-15 20:31:22 (dst=0) 20:33                                         
clk : 2020-03-15 20:31:23 (dst=0) 20:33                                         
clk : 2020-03-15 20:31:24 (dst=0) 20:33                                         
clk : 2020-03-15 20:31:25 (dst=0) 20:33                                         
```    

Maybe more importantly, the USB connector can be used to upgrade the firmware.

### Install firmware

There is a complete binary [release](sketches/WordClockFull/release) that you can flash yourself.
A PC program to flash is provided.

As an alternative you can build the binary yourself.

There are plenty of sites explaining how to install Arduino apps, 
even from [myself ](https://github.com/maarten-pennings).

Download and install [Arduino IDE](https://www.arduino.cc/en/Main/Software) and then the 
[ESP8266 compiler and libraries](https://www.instructables.com/id/Quick-Start-to-Nodemcu-ESP8266-on-Arduino-IDE/).

Download the [WordClockFull](sketches/WordClockFull).
It does need the Adafruit NeoPixel library, that you find in the Arduino Library manager.
It does need the configuration library [Cfg](https://github.com/maarten-pennings/Cfg)
and the persistent storage library [Nvm](https://github.com/maarten-pennings/Nvm)

The libraries need to be stored in the Arduino library directory
(mine is here `C:\Users\Maarten\Documents\Arduino\libraries`) and the WordClock app
itself can be stored anywhere, but most people store it in the Arduino directory
(thus `C:\Users\Maarten\Documents\Arduino\` for me).

### Normal operation

When the WordClock is powered it should start with a blank (dark) display.
Sometimes it powers with the display showing the last time (this is due to the large internal capacitor
which causes the NeoPixel display to retain state). But the firmware will immediately switch off the display.

After power up, the WordClock first gives the user the option to enter configuration mode.
Entering configuration mode is achieved by pressing the button at the back while the status LED at the back is blinking rapidly.
If the button is not pressed during the rapid blinking (which takes about one second), the WordClock app starts.
We will describe that first. Configuration mode is described [below](#configuration).

The WordClock app starts with the status LED steadily on. This indicates the WordClock has no WiFi connection (yet).
The first step of the WordClock app is a NeoPixel test: all red LEDs are turned on one-by-one, then all green LEDs and finally
all blue LEDs. 

After the NeoPixel test finishes, the display blanks. The display stays blank until time is known.
For this, the WordClock needs to connect to WiFi. Once that is successful, the status LED switches off (normal state).
Next step is to sync with NTP services. If that is successful, WordClock knows time, and shows that on the display.

If later, the WiFi connection is lost, the status LED switches on again (until the next WiFi connect).
When there is no WiFi, there is no NTP sync. But if time has been synced once, the internal processor
keeps track of time itself (with a drift of ±1s per day). NTP syncs occur once per hour (if WiFi is connected).

There is one feature while running: the button at the back toggles demo mode.
In demo mode, time runs at 15× speed. This shows off the animations.
Demo mode starts with current time, but quickly deviates because it runs faster.
When the button is pressed again, demo mode is off, and the clock shows the real time again.

When the WordClock is correctly configured (the `Timezone` field in the configuration), 
it will also switch to daylight saving time and back to standard time at the correct moment.

Note that the WordClock app logs all steps over the UART connection, which is available over USB.

### Configuration

When the user presses the back button at power up (with the status LED blinking rapidly) the WordClock enters configuration mode.
In configuration mode, the WordClock starts a WiFi Access Point, a DNS server, DHCP server and a web server.
Once the web server is running, the status LED will blink slowly (1Hz) showing configuration mode is active.

Connect your laptop or smart phone to this Access Point.
The SSID starts with WordClock, and is followed by a part of its MAC address.

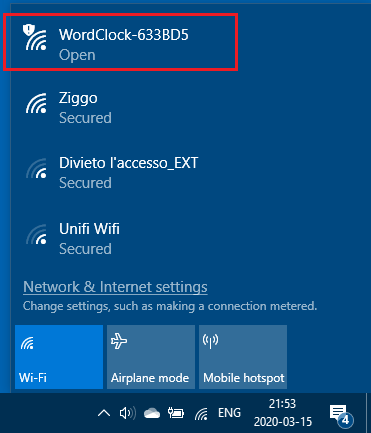
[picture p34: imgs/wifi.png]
WiFi


Start a browser (on your laptop or smart phone) and visit site 10.10.10.10.
You will get the configuration page.

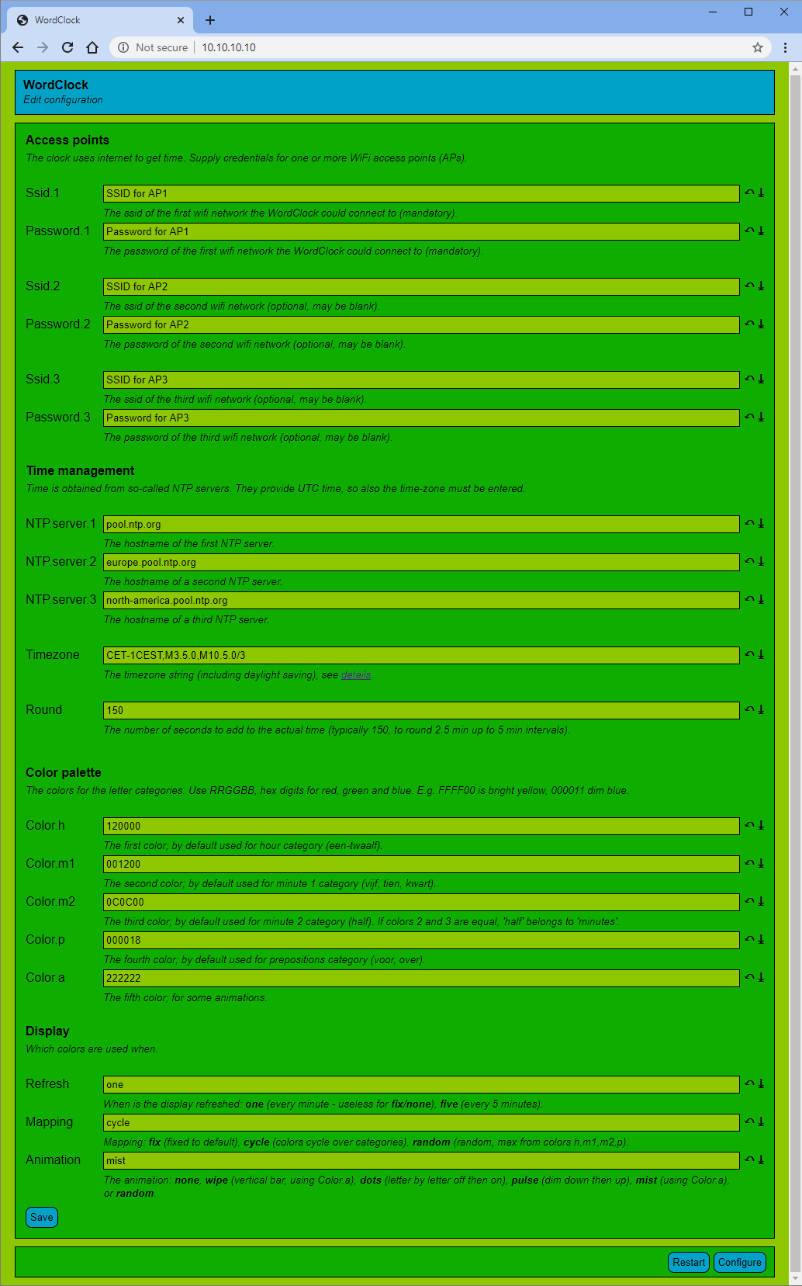
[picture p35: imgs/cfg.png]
Configuration


The configuration page consist of sections. Each section contains fields.
Each field has a name (like `Round`), a value (like `150`), and some help 
(`The number of seconds to add to the actual time (typically 150, to round 2.5 min up to 5 min intervals).`)
At the end of each field you find two arrows: an undo arrow, which undoes all edit action and reverts to the current value.
The down error reverts to the default of the field.
Once you have entered all configuration settings to you liking, press `Save`.
The settings will be saved persistently, and the WordClock restart.

The first section is **Access Points**.  
Here you can enter up to three access points; the SSID (`Ssid.1`, `Ssid.2`, and `Ssid.3`) and 
the associated passwords  (`Password.1`, `Password.2`, and `Password.3`) .
I typically enter home, work, and the tethering Access Point of my mobile phone.
If you have fewer than three, just leave them blank.
 
The next section is **Time management**.  
Here you type the host name of three NTP servers (`NTP.server.1`, `NTP.server.2`, and `NTP.server.3`). 
Probably the default servers are ok.  
The `Timezone` field defines the standard timezone you want (with respect to UTC). It also defines the daylight 
saving timezone (DST) and when it starts and stops. The syntax of this field is described 
[here](https://www.gnu.org/software/libc/manual/html_node/TZ-Variable.html).  
The `Round` field adds seconds to time to do the rounding up. See details [above](#12-model-5).

The third section is **Color palette**.  
All fields should have 6 hexadecimal digits (0..9, A..F), with two digits for red, two for green and two for blue.
The first color (`Color.h`) is used for the hour word.
The second color (`Color.m1`) is used for the minutes ("vijf", "tien", "kwart").
The third color (`Color.m2`) is used for the word "half".
The fourth color (`Color.p`) is used for the prepositions ("voor" and "over").
If `Color.m1` and `Color.m2` are equal, "half" will always be colored the same as "vijf", "tien" and "kwart" 
(in "cycle" and "random" mapping).
If mapping is "random", the RGB components of the generated random colors will always be 
below the maximum of `Color.h`, `Color.m1`, `Color.m2`, `Color.p`.  
The last color (`Color.a`) is used for animations that need an extra color ("wipe" and "mist").

The last section is **Display**.  
This section determines the animations.  
`Refresh` is either "one" or "five". It determines how often the display is refreshed:
either every minute ("one") or every five minutes ("five"). Note that only every five minutes the 
time reading actually changes (since the clock display resolution is 5 minutes).
So selecting "one" makes no sense when mapping is "fix" and animation is "none", but when mapping
is not "fix" or animation is not "none" there is a color change and/or animation every minute.
`Mapping` determines the colors used for the words. "fix" uses the colors as defined in the color palette section.  
The "cycle" mapping also uses the colors, but every refresh the colors are cycled.
Finally, the "random" mapping generates random colors for the words (never duplicates, never black).  
The `Animation` setting determines the animation for every refresh.
The "[none](https://youtu.be/OCgUQ6qWnN4)" animation instantly removes the old time and adds the new time.
The "[wipe](https://youtu.be/U9yd8xaslh4)" animation moves a column (in `Color.a`) from left to right erasing the old time in front of it and adding the new time behind it.
The "[dots](https://youtu.be/AXKME2LGA_A)" removes the old time one pixel at a time, then adds the new time one pixel at a time.
The "[pulse](https://youtu.be/F0VIralrmUM)" animation dims the old time down, then dims the new time up.
The "[mist](https://youtu.be/u285F07go_c)" animation covers the old time be adding mist pixels (`Color.a`), then uncovers the new time by removing mist pixels.
Finally, the animation "random" randomly chooses one of none, wipe, dots, pulse or mist.

## 15. Replication

I made one extra, for Marc. I made some changes.

Firstly, I got a 6V capacitor, which is much smaller than the 35V one I used before, although it has the same capacity (1000 µF). I attached the capacitor to the neopixel board instead of to the ESP board.

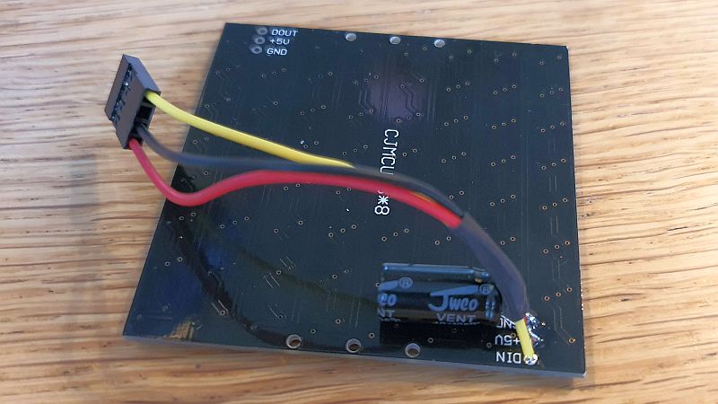
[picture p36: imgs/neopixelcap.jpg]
New Neopixel board


Secondly, I made changes to the schematic. I got rid of the level shifter, and I added a pull-up to the D3 button. The reason for the pull-up is that the first version does not always pick-up button presses for configuration.

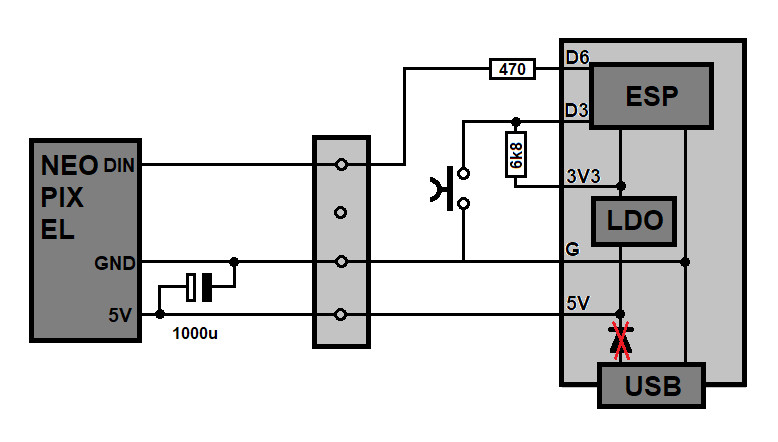
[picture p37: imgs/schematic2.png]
New schematic


I also made the "Wing PCB" a little bit bigger.

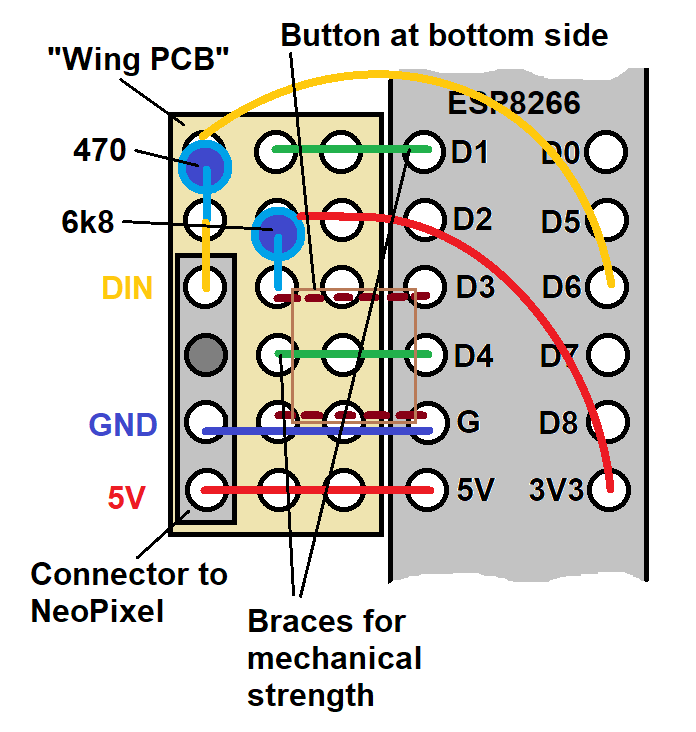
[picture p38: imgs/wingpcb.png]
Wing PCB


In the photo below, you see the wing PCB in its casing.
Note that the button is on the bottom side of the wing PCB.

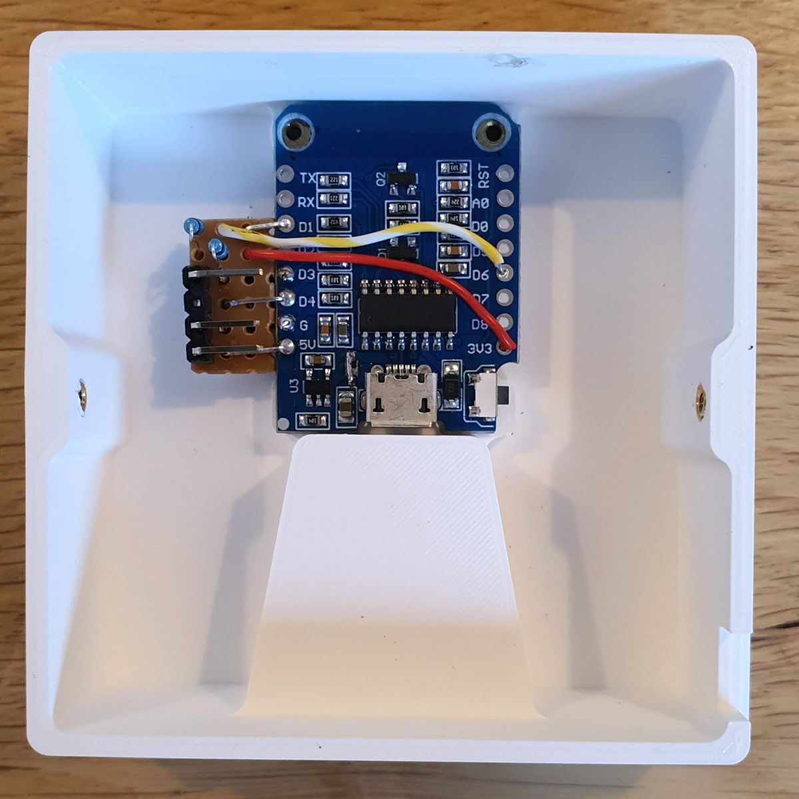
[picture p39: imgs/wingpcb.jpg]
Wing PCB


The above photo shows another change: I made the case white.
That is a mistake. The white PLA clearly does not isolate the
light. We suffer from bleed.

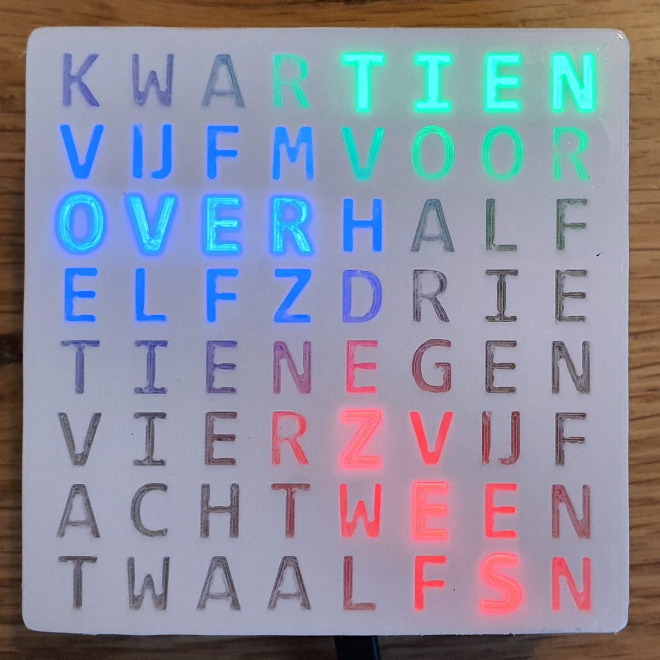
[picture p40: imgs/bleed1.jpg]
Front bleed


This is also very clear from the top.

Top bleed

I painted the inner walls that separate the LEDs with black paint.
It does help a bit.

After painting

Hmm, guess I have to print in the old color.

## 16. Delay

As a follow-up to the NeoPixel timing experiments in [8. Timing](#8-Timing) I did a final experiment.
The goal is to determine the delay caused by the daisy chain of NeoPixels.

I took the "production" NeoPixel board with 64 NeoPixels.
I put a probe of a logic analyzer on the data-in pin of the board, which is the data-in of NeoPixel 0.
I put a second probe on the data-out pin of the board, which is the data-out of NeoPixel 63 - or data-in of the non-existing NeoPixel 64.

```C
  #define NUMPIXELS      65
  for( int i=0; i<NUMPIXELS; i++ ) pixels.setPixelColor(i, i*0x010203 );
  pixels.show();
```

I wrote the above small test loop. 
It configures _65_ pixels (numbered 0 up to and including 64). Since this is one more pixel than is present 
on the board, the data-out pin of the board will show the data send to this non-existing NeoPixel 64.

Note that the loop sets the red value of NeoPixel _i_ to the value _i_, the green value to _2×i_,
and the blue value to _3×i_. In other words, NeoPixel 64 will be configured to R=64, G=128, B=192.
The call to `pixels.show()` we start transmitting the 3×8×65 pulses to the board.

NeoPixel delay

 - The top of the picture shows a trace of the two signals:
   the signal on _board data-in_ (NewPixel 0 data-in) and the signal on _board data-out_ (NeoPixel 63 data-out, NeoPixel 64 data-in).
 - Sending the RGB data to the board takes, as before ~2ms (the wide gray rectangle in the top trace). 
 - All the 3×8×65 pulses pass NeoPixel 0, but NeoPixel 64 only sees the remaining 3×8×1 pulses for itself
   (the small gray rectangle in the top trace). 
 - The bottom of the picture shows the same trace, but zoomed in (as indicated in yellow) on the end of the trace.
 - NeoPixel 64 will be configured to G=128, R=64, B=192; 
   we see those pulses pass as the last ones on data-in of NeoPixel 0.
   This does mean that the daisy-chained NeoPixels are not one big shift register: 
   the data for NeoPixel 64 is not shifted-in as first, but as last.
   This is confirmed by the [WS2812B datasheet](https://cdn-shop.adafruit.com/datasheets/WS2812B.pdf):
   _"the first pixel collect initial 24bit data then sent to the internal data latch, 
   the other data [...] sent to the next cascade pixel"_.
 - The pulses are passed on by NeoPixel 0 to NeoPixel 1, which passes it on to 2, etc, until they arrive on the data-in of NeoPixel 64.
 - We see that the chain of 64 NeoPixels causes a delay of 9.13µs (cyan rectangle for marker pair A1-A2).
 - It _could_ be that a NeoPixel is "activated" - starts illuminating using its new settings - once the data 
   is in "the internal data latch" as the datasheet mentions.
   This would mean that the activation of the first and last NeoPixels is ~2000µs apart.
 - It _could_ also be that a NeoPixel is only activated (settings copied from latch to the RGB led drivers) 
   when the RET code is detected (a silent period of 50 µs). 
   This would mean that the activation of the first and last NeoPixels is only 9.13µs apart.

In an attempt to determine the activation moment, I've changed the setup a bit.
I added a third probe, an analogue measurement of Vcc.
Secondly, the Arduino script is changed: all pixels are set to full brightness `pixels.setPixelColor(i,0xffffff)`.
Thirdly, I power the board now via a powered USB hub.

The idea is that setting all NeoPixels from off to maximum causes a drop in voltage 
(due to power suddenly going from 100mA to 2500mA). The question being: is this voltage drop 
gradual during the configuration, or abrupt when the RET signal comes in.

NeoPixel activation

The above capture shows a rather constant voltage of 4V4 before sending the pulses.
When all pulses are send, at 2ms after T=0 (green arrow in left image), the voltage gradually drops to 3V3.
This seems to support the hypothesis that NeoPixels are activated when the RET code is received.

Especially, because if we zoom in on the green arrow (right image), we see a plateau 
at the original 4V4 that has a width of about T_RET (50us). This seems to indicate that
T_RET us after the end of configuration, the LEDs are switched full on and the voltage starts to drop.

## Todo

- add cfg option for pulsating seconds
- add animation **slide** (letters out of view)

(end)

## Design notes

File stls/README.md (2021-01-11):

# WordClock - STLs

The STL files I made for the WordClock.

## Notes

The following STL files are available. See below for the clickable images.
 1. [Back of the box](WordClockBack-v13.stl)
 2. [Front of the box](WordClockFront-v13-box.stl)  
    The front is supposed to be printed with a two-nozzle printer. 
    One nozzle prints "black" (the case) and one nozzle prints "transparent" (the letters).
 3. [Letters](WordClockFront-v13-letters.stl)
 4. [Letters with front](WordClockFront-v13-letters-withfront.stl)  
    Alternative for 3; the letters have an additional transparent front plane.
 5. [Front of box + Letters in STEP](WordClockFront-v13.step)  
    Alternative for 2+3 together in STEP format.

When setting up the "front of box" print job: see here how to align the case with the letters.

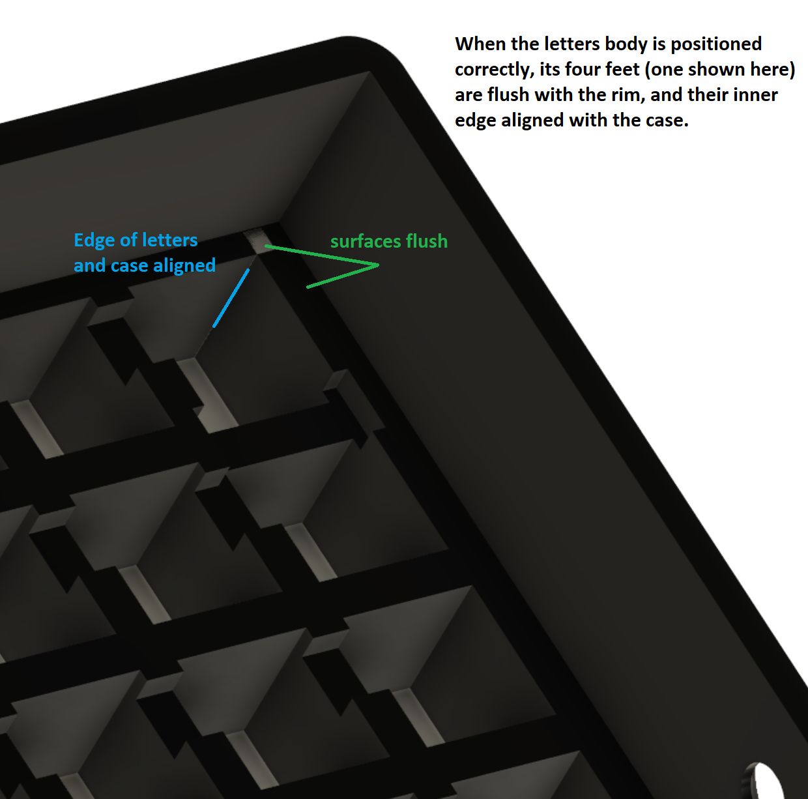
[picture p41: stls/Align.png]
Align


## Back (of the box)

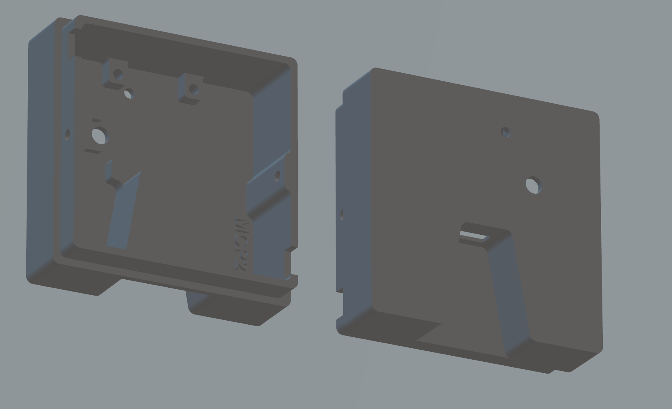
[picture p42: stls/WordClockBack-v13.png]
Back


## Front (of the box)

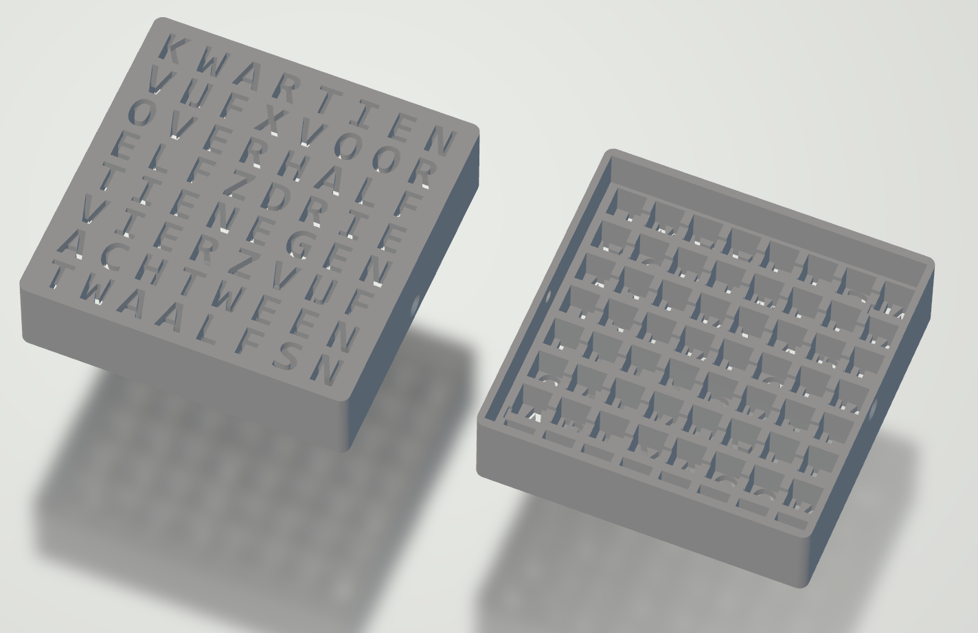
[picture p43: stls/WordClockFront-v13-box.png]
Front


## Transparent letters on diffuser

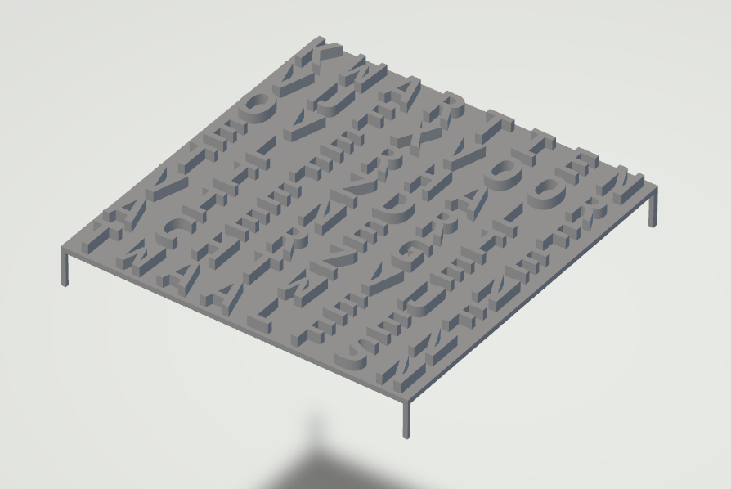
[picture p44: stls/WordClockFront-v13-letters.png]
Letters


## Transparent letters on diffuser (with extra front pane)

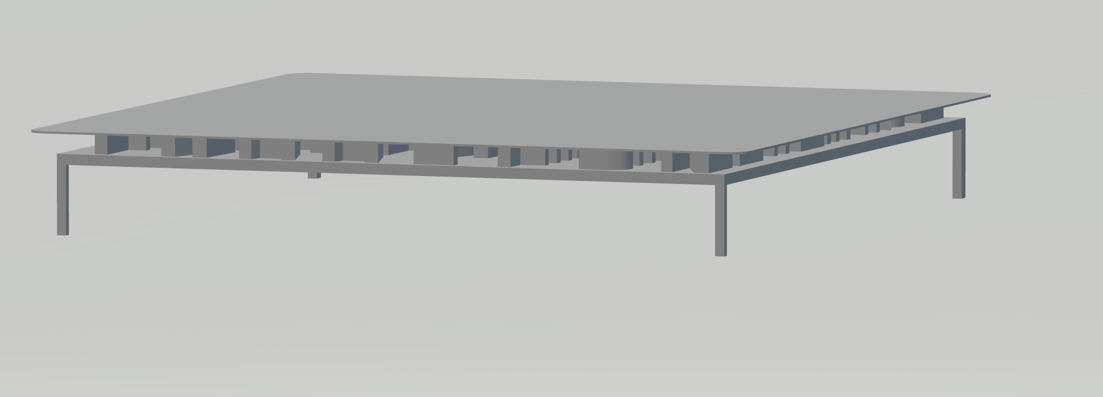
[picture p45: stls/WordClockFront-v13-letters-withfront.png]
Letters with front


(end)

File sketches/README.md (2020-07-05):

# Sketches

This directory contains Arduino sketches used in the [WordClock](https://github.com/maarten-pennings/WordClock) project.
All sketches are intended for an ESP8266.

 - [WordClockLed](WordClockLed)  
   A clock that tells time, in Dutch, in steps of 5 minutes on a MAX7221 controlled 8x8 LED matrix.
   The clock is hand-set (with flash button) and runs on ESP8266 crystal.
   It also has a demo mode: every 0.1ms the clock advances 1 minute.
   
 - [NeoPixelAmps](NeoPixelAmps)  
   Sketch used to measure power used by NeoPixels.
   Used for electronics design: determine how many amps are needed.
   
 - [WordClockNeo](WordClockNeo)  
   A clock that tells time, in Dutch, in steps of 5 minutes on a NeoPixel 8x8 LED matrix.
   The clock is hand-set (with flash button) and runs on ESP8266 crystal
   It also has a demo mode: every 0.1ms the clock advances 1 minute

 - [TimeKeeping](TimeKeeping)  
   Keep track of time via NTP servers; local time zone and daylight saving time included.
   This is just time keeping. In a later step, this is integrated into `WordClockNeo`
   resulting in `WordClockSimple`.

 - [NeoPixelTest](NeoPixelTest)  
   Sketch used to test all 3 LEDs in all 64 NeoPixels.
   Written to validate the electrical design.

 - [WordClockSimple](WordClockSimple)  
   A WordClock using NeoPixels, keeping time via NTP.
   All configuration choices hardwired in sketch.  
   This is the one that you might be looking for if you want a working but simple clock.

 - [WordClockFull](WordClockFull)  
   A wordClock using NeoPixels, keeping time via NTP, with dynamic configuration (via web).
   Supports color changes and display animations. Has a demo mode.
   This is the one that you might be looking for if you want a full featured clock.
   See the [main page](../README.md#13-Model-6) for a list of features and user manual.
   See the [release](WordClockFull/release/readme.md) for a binary release.
    
(end of doc)

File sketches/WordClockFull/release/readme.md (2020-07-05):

# Release

This directory contains a binary release of WorClockFull.
This should make it easier to flash your own.

## How to flash

The easiest way to flash the binary is to use my [flash tool](https://github.com/maarten-pennings/flasher).
It is a batch file around the official flasher `esptool` for the ESP8266 (note, the `esptool` has been superseded by something newer).

- Download the flasher tool into a directory on your PC
- Copy the [`WordClockFull.ino.bin`](WordClockFull.ino.bin) into the same directory
- Run the batch file (e.g. double click it)

## Versions

The binary was made with the Arduino IDE.
The following ingredients were used

- Arduino IDE 1.8.11  
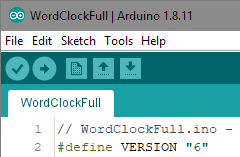
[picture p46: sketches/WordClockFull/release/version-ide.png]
Arduino IDE
  
- ESP9266 board 2.6.3  
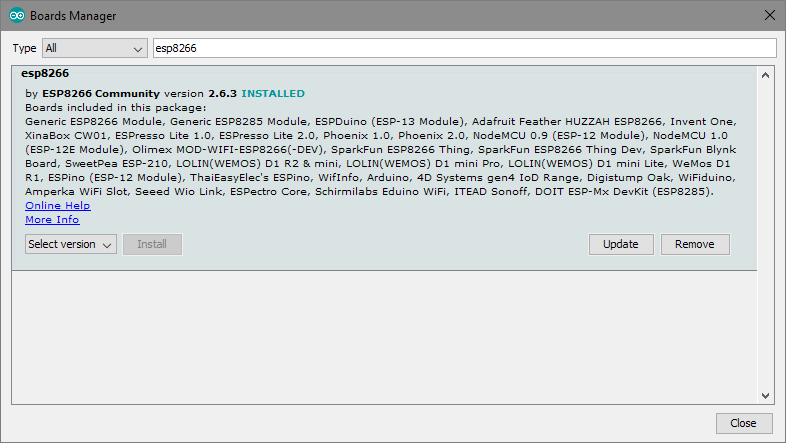
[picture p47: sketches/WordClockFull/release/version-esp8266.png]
ESP8266 board
  
- Node MCU 1.0 (ESP-12E Module), ...  
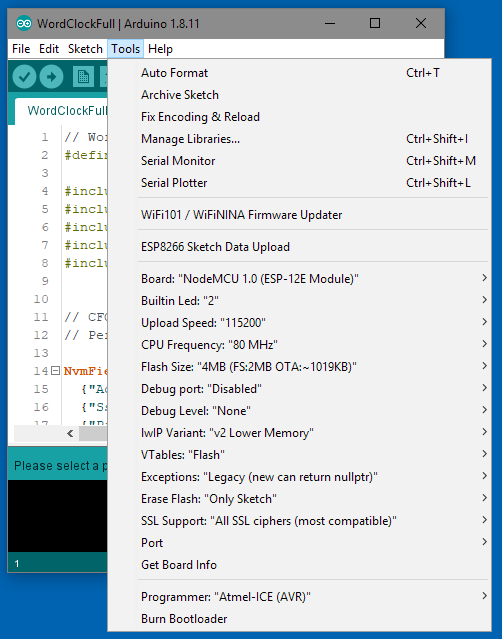
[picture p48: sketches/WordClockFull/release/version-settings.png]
Node MCU 1.0 (ESP-12E Module
  
- NeoPixel 1.3.4  
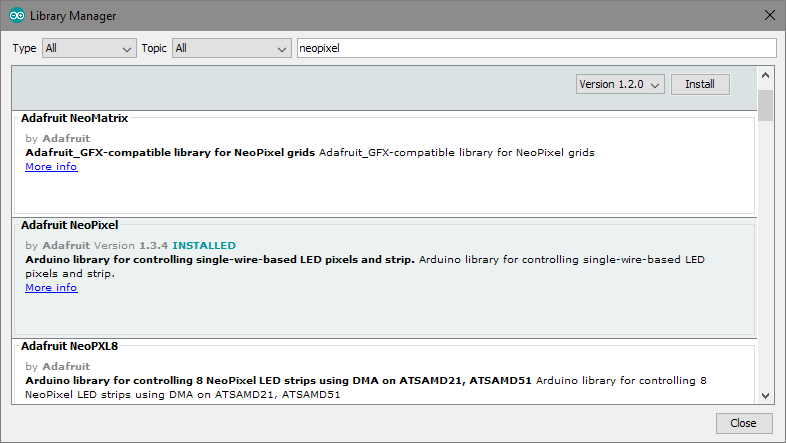
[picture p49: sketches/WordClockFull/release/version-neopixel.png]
NeoPixel
  
- Cfg 1.7.0  
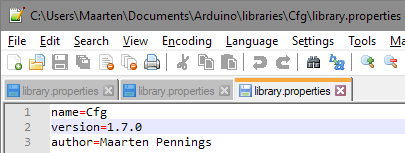
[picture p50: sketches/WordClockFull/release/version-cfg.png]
Cfg
  
- Nvm 1.2.0  
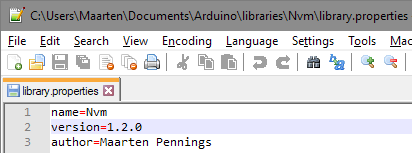
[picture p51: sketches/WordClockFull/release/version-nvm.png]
Nvm
  

(end of doc)

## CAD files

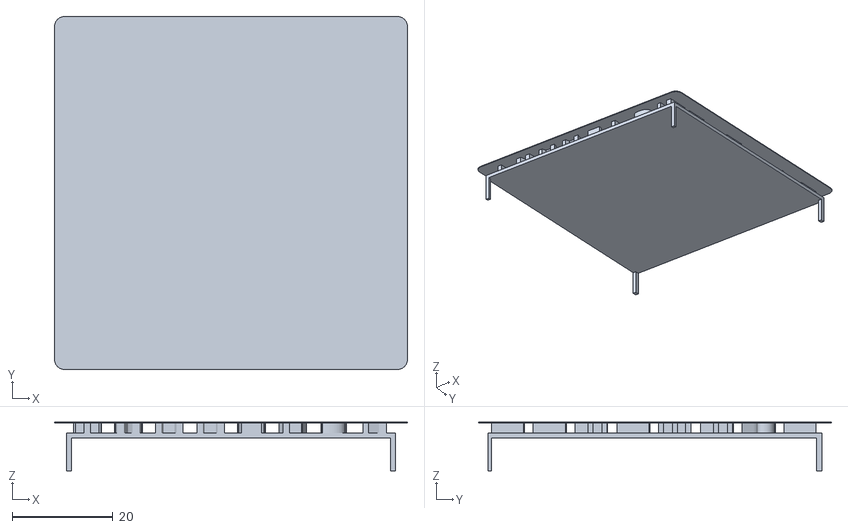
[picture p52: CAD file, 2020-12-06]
stls/WordClockFront-v13-letters-withfront.stl
70.0 x 70.0 x 9.70

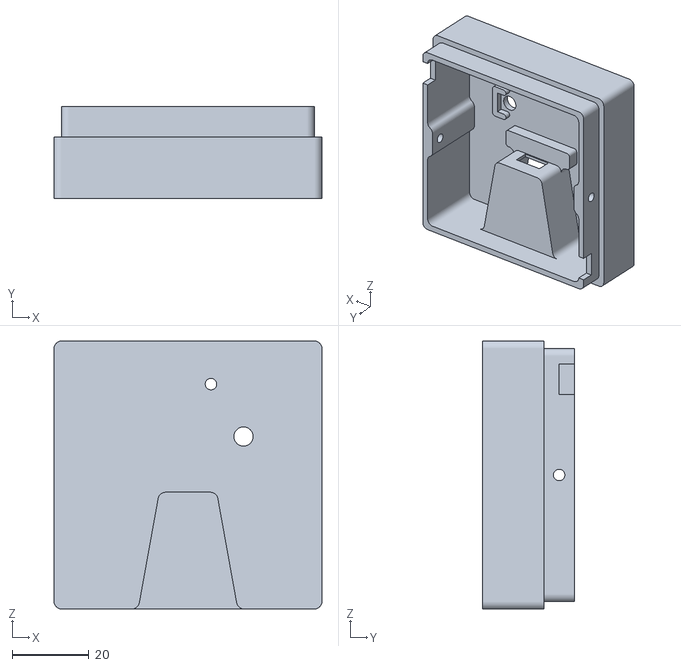
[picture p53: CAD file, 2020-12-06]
stls/WordClockBack-v13.stl
70.0 x 24.0 x 70.0

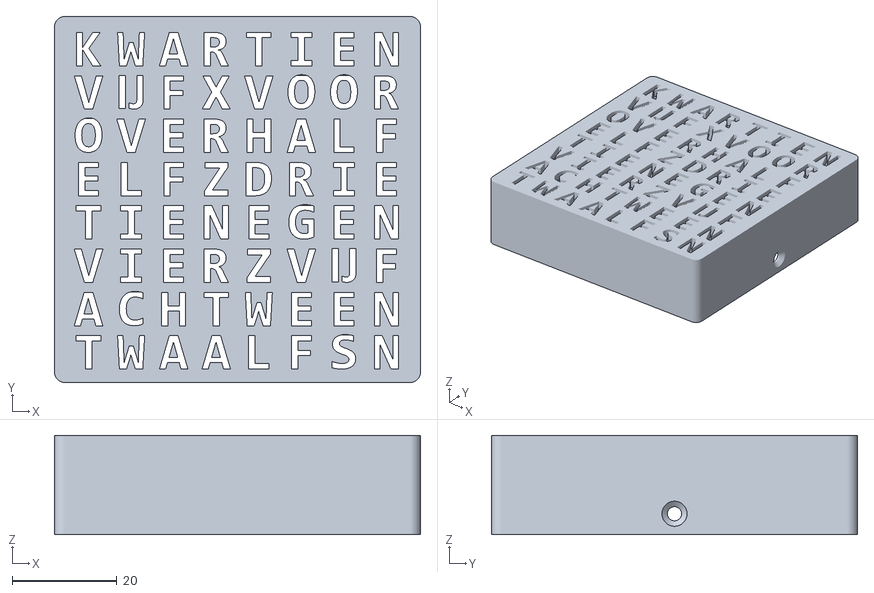
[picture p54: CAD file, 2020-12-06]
stls/WordClockFront-v13-box.stl
70.0 x 70.0 x 19.0

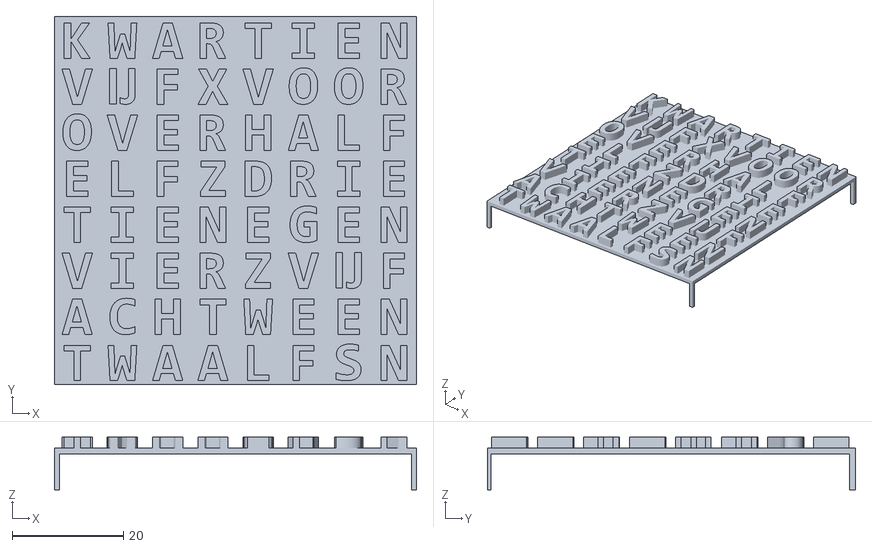
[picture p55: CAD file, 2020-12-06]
stls/WordClockFront-v13-letters.stl
65.1 x 66.3 x 9.50

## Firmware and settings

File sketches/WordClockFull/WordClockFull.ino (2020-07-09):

// WordClockFull.ino - A wordClock using NeoPixels, keeping time via NTP, with dynamic configuration, color
#define VERSION "7"

#include <coredecls.h> // Only needed for settimeofday_cb()
#include <time.h>
#include <ESP8266WiFi.h>
#include <ESP8266WiFiMulti.h>
#include <Adafruit_NeoPixel.h>
#include <Cfg.h> // A library that lets a user configure an ESP8266 app (https://github.com/maarten-pennings/Cfg)


// CFG (configuration) ==========================================================================
// Persistent storage of configuration parameters

NvmField cfg_fields[] = {
  {"Access points"   , ""                           ,  0, "The clock uses internet to get time. Supply credentials for one or more WiFi access points (APs). " },
  {"Ssid.1"          , "SSID for AP1"               , 32, "The ssid of the first wifi network the WordClock could connect to (mandatory)." },
  {"Password.1"      , "Password for AP1"           , 32, "The password of the first wifi network the WordClock could connect to (mandatory). "},
  {"Ssid.2"          , "SSID for AP2"               , 32, "The ssid of the second wifi network (optional, may be blank)." },
  {"Password.2"      , "Password for AP2"           , 32, "The password of the second wifi network (optional, may be blank). "},
  {"Ssid.3"          , "SSID for AP3"               , 32, "The ssid of the third wifi network (optional, may be blank)." },
  {"Password.3"      , "Password for AP3"           , 32, "The password of the third wifi network (optional, may be blank). "},
  
  {"Time management" , ""                           ,  0, "Time is obtained from so-called NTP servers. They provide UTC time, so also the time-zone must be entered. " },
  {"NTP.server.1"    , "pool.ntp.org"               , 32, "The hostname of the first NTP server." },
  {"NTP.server.2"    , "europe.pool.ntp.org"        , 32, "The hostname of a second NTP server." },
  {"NTP.server.3"    , "north-america.pool.ntp.org" , 32, "The hostname of a third NTP server. " },
  {"Timezone"        , "CET-1CEST,M3.5.0,M10.5.0/3" , 48, "The timezone string (including daylight saving), see <A href='https://www.gnu.org/software/libc/manual/html_node/TZ-Variable.html'>details</A>. " },
  {"Round"           , "150"                        ,  4, "The number of seconds to add to the actual time (typically 150, to round 2.5 min up to 5 min intervals). " },
  
  {"Color palette"   , ""                           ,  0, "The colors for the letter categories. Use RRGGBB, hex digits for red, green and blue. E.g. FFFF00 is bright yellow, 000011 dim blue. " },
  {"Color.h"         , "120000"                     ,  6, "The first color; by default used for hour category (een-twaalf)." },
  {"Color.m1"        , "001200"                     ,  6, "The second color; by default used for minute 1 category (vijf, tien, kwart)." },
  {"Color.m2"        , "0C0C00"                     ,  6, "The third color; by default used for minute 2 category (half). If colors 2 and 3 are equal, 'half' belongs to 'minutes'." },
  {"Color.p"         , "000018"                     ,  6, "The fourth color; by default used for prepositions category (voor, over)." },
  {"Color.a"         , "222222"                     ,  6, "The fifth color; for some animations. " },
  
  {"Display"         , ""                           ,  0, "Which colors are used when. " },
  {"Refresh"         , "one"                        ,  8, "When is the display refreshed: <b>one</b> (every minute - useless for <b>fix</b>/<b>none</b>), <b>five</b> (every 5 minutes)." },
  {"Mapping"         , "cycle"                      ,  8, "Mapping: <b>fix</b> (fixed to default), <b>cycle</b> (colors cycle over categories), <b>random</b> (random, max from colors h,m1,m2,p)." },  
  {"Animation"       , "mist"                       ,  8, "The animation: <b>none</b>, <b>wipe</b> (vertical bar, using Color.a), <b>dots</b> (letter by letter off then on), <b>pulse</b> (dim down then up), <b>mist</b> (using Color.a), or <b>random</b>. " },  
  {0                 , 0                            ,  0, 0},  
};

#define CFG_BUT_PIN 0

Cfg cfg("WordClock", cfg_fields, CFG_SERIALLVL_USR, LED_BUILTIN);


// COL (Color) ================================================================================
// Color management (palettes)

typedef struct { // Colors for the words
  uint32_t h;  // Color for hours
  uint32_t m1; // Color for minutes (vijf, tien, kwart)
  uint32_t m2; // Color for minutes (half)
  uint32_t p;  // Color for prepositions (voor, over)
} palette4_t;

typedef struct { // Color component maxima for random
  uint32_t r; // The maximum r (red) value in palette5
  uint32_t g; // The maximum g (green) value in palette5
  uint32_t b; // The maximum b (blue) value in palette5
} palette3_t;

typedef struct { // Colors from config
  uint32_t h; 
  uint32_t m1;
  uint32_t m2;
  uint32_t p;
  uint32_t a;
} palette5_t;

// Values retrieved from Cfg

palette5_t col_palette;        // The colors as configured by the user
palette3_t col_maxima;         // Maxima from col_palette - see col_init()

#define COL_REFRESH_ONE      1 // cfg string: one
#define COL_REFRESH_FIVE     5 // cfg string: five
int col_refresh;   

#define COL_MAPPING_FIX      1 // cfg string: fix
#define COL_MAPPING_CYCLE    2 // cfg string: cycle
#define COL_MAPPING_RANDOM   3 // cfg string: random
int col_mapping;   

#define COL_ANIMATION_NONE   1 // cfg string: none
#define COL_ANIMATION_WIPE   2 // cfg string: wipe
#define COL_ANIMATION_DOTS   3 // cfg string: dots
#define COL_ANIMATION_PULSE  4 // cfg string: pulse
#define COL_ANIMATION_MIST   5 // cfg string: mist
#define COL_ANIMATION_RANDOM 6 // cfg string: random // must be the last in the enum - see AnimRandom::start()
int col_animation; 

// The parse and unparse routines

// Parses a string, which must consist of 6 hex digits (0-9,a-f,A-F). Returns the integer value (0x101010 on syntax error).
uint32_t col_parse(const char * cfgid) {
  char * val= cfg.getval(cfgid);
  if( strlen(val)==6 ) {
    int ishex= true;
    uint32_t col= 0;
    for(int i=0; i<6; i++) {
      col<<=4;
      if(      '0'<=val[i] && val[i]<='9' ) col+= val[i]-'0';
      else if( 'a'<=val[i] && val[i]<='f' ) col+= val[i]-'a'+10;
      else if( 'A'<=val[i] && val[i]<='F' ) col+= val[i]-'A'+10;
      else ishex= false;
    }
    if( ishex ) return col;
  }
  Serial.printf("col : ERROR in %s (%s)\n",cfgid,val);
  return 0x101010; // Not 6 hex digits, return grey
}

// Converts an integer refresh value (one, five) to a string.
const char * col_refresh_unparse(int val) {
  if(      val==COL_REFRESH_ONE  ) return "one";
  else if( val==COL_REFRESH_FIVE ) return "five";
  else return "?refresh?";
}

// Converts a string refresh value (one, five) to an integer.
int col_refresh_parse() {
  const char * cfgid= "Refresh";
  char * val= cfg.getval(cfgid);
  if( strcmp(val,"one" )==0 ) return COL_REFRESH_ONE;
  if( strcmp(val,"five")==0 ) return COL_REFRESH_FIVE;
  int dft= COL_REFRESH_ONE;
  Serial.printf("col : ERROR in %s (%s->%s)\n",cfgid,val,col_refresh_unparse(dft));
  return dft;
}

// Converts an integer mapping value (fix, cycle, random) to a string.
const char * col_mapping_unparse(int val) {
  if(      val==COL_MAPPING_FIX    ) return "fix";
  else if( val==COL_MAPPING_CYCLE  ) return "cycle";
  else if( val==COL_MAPPING_RANDOM ) return "random";
  else return "?mapping?";
}

// Converts a string mapping value (fix, cycle, random) to an integer.
int col_mapping_parse() {
  const char * cfgid= "Mapping";
  char * val= cfg.getval(cfgid);
  if( strcmp(val,"fix"    )==0 ) return COL_MAPPING_FIX;
  if( strcmp(val,"cycle"  )==0 ) return COL_MAPPING_CYCLE;
  if( strcmp(val,"random" )==0 ) return COL_MAPPING_RANDOM;
  int dft= COL_MAPPING_CYCLE;
  Serial.printf("col : ERROR in %s (%s->%s)\n",cfgid,val,col_mapping_unparse(dft));
  return dft;
}

// Converts an integer animation value (none, wipe, dots, pulse, mist, random) to a string.
const char * col_animation_unparse(int val) {
  if(      val==COL_ANIMATION_NONE  ) return "none";
  else if( val==COL_ANIMATION_WIPE  ) return "wipe";
  else if( val==COL_ANIMATION_DOTS  ) return "dots";
  else if( val==COL_ANIMATION_PULSE ) return "pulse";
  else if( val==COL_ANIMATION_MIST  ) return "mist";
  else if( val==COL_ANIMATION_RANDOM) return "random";
  else return "?animation?";
}

// Converts a string animation value (none, wipe, dots, pulse, mist) to an integer.
int col_animation_parse() {
  const char * cfgid= "Animation";
  char * val= cfg.getval(cfgid);
  if( strcmp(val,"none"  )==0 ) return COL_ANIMATION_NONE;
  if( strcmp(val,"wipe"  )==0 ) return COL_ANIMATION_WIPE;
  if( strcmp(val,"dots"  )==0 ) return COL_ANIMATION_DOTS;
  if( strcmp(val,"pulse" )==0 ) return COL_ANIMATION_PULSE;
  if( strcmp(val,"mist"  )==0 ) return COL_ANIMATION_MIST;
  if( strcmp(val,"random")==0 ) return COL_ANIMATION_RANDOM;
  int dft= COL_ANIMATION_MIST;
  Serial.printf("col : ERROR in %s (%s->%s)\n",cfgid,val,col_animation_unparse(dft));
  return dft;
}

// Macros to unpack the components from a color, or repack the components to a color.
#define R(u)       (((u)>>16)&0xFF)
#define G(u)       (((u)>> 8)&0xFF)
#define B(u)       (((u)>> 0)&0xFF)
#define RGB(r,g,b) ((r)<<16) | ((g)<<8) | ((b)<<0)

// Initializes the color driver.
// Gets the user (color/animation) configuartion, parses that, and stores that in global variables (they never change).
void col_init() {
  col_palette.h = col_parse( "Color.h" );
  col_palette.m1= col_parse( "Color.m1" );
  col_palette.m2= col_parse( "Color.m2" );
  col_palette.p = col_parse( "Color.p" );
  col_palette.a = col_parse( "Color.a" );
  Serial.printf("col : palette: %06X %06X %06X %06X %06X\n", col_palette.h, col_palette.m1, col_palette.m2, col_palette.p, col_palette.a );

  col_maxima.r= max( max( R(col_palette.h) , R(col_palette.m1) )  ,  max( R(col_palette.m2) , R(col_palette.p) ) );
  col_maxima.g= max( max( G(col_palette.h) , G(col_palette.m1) )  ,  max( G(col_palette.m2) , G(col_palette.p) ) );
  col_maxima.b= max( max( B(col_palette.h) , B(col_palette.m1) )  ,  max( B(col_palette.m2) , B(col_palette.p) ) );
  Serial.printf("col : max: R%02X G%02X B%02X\n", col_maxima.r, col_maxima.g, col_maxima.b );

  col_refresh= col_refresh_parse();
  col_mapping= col_mapping_parse();
  col_animation= col_animation_parse();
  Serial.printf("col : modes: %s %s %s\n", col_refresh_unparse(col_refresh), col_mapping_unparse(col_mapping), col_animation_unparse(col_animation) );
}

// Generating the right color

// Multiplies R, G, and B components of `col` with scale/255, and returns that color.
uint32_t col_scale(int scale, uint32_t col) { // scale = 0..255
  //Serial.printf("\n");
  //Serial.printf("scale=%d, col=%06x\n", scale, col);
  uint32_t r= ( R(col) * scale ) / 255;
  //Serial.printf("r=%06x\n", r);
  uint32_t g= ( G(col) * scale ) / 255;
  //Serial.printf("r=%06x\n", g);
  uint32_t b= ( B(col) * scale ) / 255;
  //Serial.printf("r=%06x\n", b);
  // Compose
  uint32_t c= RGB(r,g,b);
  //Serial.printf("c=%06x\n", c);
  return c;
}

// Returns the color half way `col1` and `col2`.
uint32_t col_merge(uint32_t col1, uint32_t col2) {
  #define M(comp1,comp2) (((comp1)+(comp2))/2)
  uint32_t r= M( R(col1) , R(col2) );
  uint32_t g= M( G(col1) , G(col2) );
  uint32_t b= M( B(col1) , B(col2) );
  // Compose
  uint32_t c= RGB(r,g,b);
  return c;
}

// Returns a random color, using global `col_maxima` as maxima for the R, G, and B components.
// Will not returnd black (0x000000); has a 75% preference for max; and a 25% preference for below max (quantized to 5).
uint32_t col_random() {
  // If we do truly random, colors get a bit washed out and equal, or even black. Introduce bias to hi.
  // We generate a 3 bit vector telling which of the (r,g,b) components are included
  int included= random(1,8); // Range [1..7], in binary (000,111], so black is not generated.
  uint32_t r= 0; // off
  if( included & 1 ) {
    r= col_maxima.r; // max
    if( random(4)==3 ) r= random(r/5)*5+5; // In steps of 5, minimum 5
  }
  uint32_t g= 0; // off
  if( included & 2 ) {
    g= col_maxima.g; // max
    if( random(4)==3 ) g= random(g/5)*5+5; // In steps of 5, minimum 5
  }
  uint32_t b= 0; // off
  if( included & 4 ) {
    b= col_maxima.b; // max
    if( random(4)==3 ) b= random(b/5)*5+5; // In steps of 5, minimum 5
  }
  // Compose
  uint32_t c= RGB(r,g,b);
  return c;
}

// Returns the "next" color, given the global variables `col_mapping` and `col_palette`.
// For mapping "fix" it is always the same colors from `col_palette`, when mapping is "cycle" it cycles the colors from `col_palette`.
// For mapping "random" generates distinct random colors.
// When col_palette.m1==col_palette.m2, "half" will always have the same color as the "minutes".
palette4_t * col_next() {
  static palette4_t palette;
  static int first=1;

  switch( col_mapping ) {
    
    case COL_MAPPING_FIX    :
        palette.h = col_palette.h;
        palette.m1= col_palette.m1;
        palette.m2= col_palette.m2;
        palette.p = col_palette.p;
      break;
      
    case COL_MAPPING_CYCLE  :
      if( first ) {
        // Initialize from color palette
        palette.h = col_palette.h;
        palette.m1= col_palette.m1;
        palette.m2= col_palette.m2;
        palette.p = col_palette.p;
      } else {
        // Cycle
        if( col_palette.m1==col_palette.m2 ) { 
          // special case: m1==m2 -> 'half' belongs to minute category
          uint32_t tmp= palette.h;
          palette.h= palette.m2; // == m1
          palette.m1= palette.m2= palette.p;
          palette.p= tmp;        
        } else {
          // 'half' has own category
          uint32_t tmp= palette.h;
          palette.h= palette.m2;
          palette.m2= palette.p;
          palette.p= palette.m1;
          palette.m1= tmp;
        }    
      }
      break;
      
    case COL_MAPPING_RANDOM :
      // Generate random but unique colors
      palette.h = col_random();
      do { palette.m1= col_random(); } while( palette.h==palette.m1 );
      do { palette.m2= col_random(); } while( palette.h==palette.m2 || palette.m1==palette.m2 );
      do { palette.p = col_random(); } while( palette.h==palette.p  || palette.m1==palette.p  || palette.m2==palette.p );
      // special case: c2==c3 -> 'half' belongs to minute category
      if( col_palette.m1==col_palette.m2 ) palette.m2= palette.m1; 
      break;
  }

  // No longer first time
  first= 0;
  
  // Return (pointer to) locally statically stored palette
  return &palette;
}


// BUT (button) ==========================================================================
// Driver for the built-in button - used for user input (configure, demo)

#define BUT_PIN 0

// The button state of the last two `but_scan` calls.
int but_state_prev;
int but_state_cur;

// Scans the button state and records that.
void but_scan() {
  but_state_prev= but_state_cur;
  but_state_cur= digitalRead(BUT_PIN)==0;
}

// Returns true when the button was pressed during the last `but_scan` and not pressed during the `but_scan` before that.
int but_wentdown() {
  return (but_state_prev!=but_state_cur) && but_state_cur;
}

// Initializes the button driver.
// Configures the GPIO block for the button pin.
void but_init() {
  pinMode(BUT_PIN, INPUT);
  but_scan();
  but_scan();
  Serial.printf("but : init\n");
}


// LED (signal LED) ==========================================================================
// Driver for the built-in LED - used for simple signalling to the user

#define LED_PIN LED_BUILTIN

// Switches the signalling LED on the ESP8266 board off.
void led_off() {
  digitalWrite(LED_PIN, HIGH); // low active
}

// Switches the signalling LED on the ESP8266 board on.
void led_on() {
  digitalWrite(LED_PIN, LOW); // low active
}

// Switches the signalling LED on the ESP8266 board to `on`.
void led_set(int on) {
  digitalWrite(LED_PIN, !on); // low active
}

// Toggles the signalling LED on the ESP8266 board.
void led_tgl() {
  digitalWrite(LED_PIN, !digitalRead(LED_PIN) );
}

// Initializes the LED driver.
// Configures the GPIO block for the LED pin.
void led_init() {
  pinMode(LED_PIN, OUTPUT);
  led_off();
  Serial.printf("led : init\n");
}


// WIFI (WiFi access points) =========================================================================
// Driver for WiFi and connection status

void wifi_sethostname(int len=WL_MAC_ADDR_LENGTH) {
  const char prefix[]= "WordClock-";
  char hname[sizeof(prefix)+2*WL_MAC_ADDR_LENGTH]; // sizeof(prefix) includes terminating 0
  char * p= (char*)&hname;
  for( const char * q=prefix; *q!=0; ) *p++= *q++;
  uint8_t macbuf[WL_MAC_ADDR_LENGTH];
  WiFi.macAddress(macbuf);
  for(int i=WL_MAC_ADDR_LENGTH-len; i<WL_MAC_ADDR_LENGTH; i++ ) {
    uint8 d1=(macbuf[i]>>4)&0x0f;
    uint8 d0=(macbuf[i]>>0)&0x0f;
    *p++= d1>=10 ? d1+'A'-10 : d1+'0';
    *p++= d0>=10 ? d0+'A'-10 : d0+'0';
  }
  *p= '\0';
  WiFi.hostname(hname);
  Serial.printf("wifi: host: %s\n", hname);
}

ESP8266WiFiMulti wifiMulti;

// Initializes the WiFi driver.
// Sets up WiFi for the three SSIDs the user configured.
void wifi_init() {
  wifi_sethostname(3);
  WiFi.persistent(false);
  WiFi.mode(WIFI_STA);
  Serial.printf("wifi: init:");

  // Get AP's from config. 1st is mandatory, others are optional
  if( cfg.getval("Ssid.1")[0]!='0' ) {
    wifiMulti.addAP( cfg.getval("Ssid.1"), cfg.getval("Password.1") );
    Serial.printf(" %s",cfg.getval("Ssid.1"));
  }
  if( cfg.getval("Ssid.2")[0]!='0' ) {
    wifiMulti.addAP( cfg.getval("Ssid.2"), cfg.getval("Password.2") );
    Serial.printf(" %s",cfg.getval("Ssid.2"));
  }
  if( cfg.getval("Ssid.3")[0]!='0' ) {
    wifiMulti.addAP( cfg.getval("Ssid.3"), cfg.getval("Password.3") );
    Serial.printf(" %s",cfg.getval("Ssid.3"));
  }

  Serial.printf("\n");
}

// Prints WiFi status to the user (over Serial, only when changed), and shows it via the signalling LED.
bool wifi_check() {
  static bool wifi_on= false;
  if( wifiMulti.run()==WL_CONNECTED ) {
    if( !wifi_on ) Serial.printf("wifi: connected to %s, IP address %s\n", WiFi.SSID().c_str(), WiFi.localIP().toString().c_str() );
    wifi_on= true;
  } else {
    if( wifi_on ) Serial.printf("wifi: disconnected\n" );
    wifi_on= false;    
  }
  led_set(!wifi_on); // signals wifi status to user (off=connected)
  return wifi_on;
}


// Clk (clock/time) ========================================================================
// Maintains local time, using NTP servers plus timezone settings

// Global variables when the clock runs in demo mode
int      clk_demo_mode;
int      clk_demo_hour;
int      clk_demo_min;
uint32_t clk_demo_ms;
#define  CLK_DEMO_MS   4000 // In demo mode, every CLK_DEMO_MS advance 1 minute

// This function is the equivalent of clk_get(): it generates time in demo mode (much faster).
bool clk_demo(int*hour, int*min, int*sec, char*buf ) {
  uint32_t now= millis();
  if( now-clk_demo_ms>CLK_DEMO_MS ) {
    clk_demo_min++;
    if( clk_demo_min==60 ) {
      clk_demo_min=0;
      clk_demo_hour++;
      if( clk_demo_hour==24 ) clk_demo_hour=0;
    }
    clk_demo_ms= now;
  }
  if( buf ) sprintf(buf,"(demo) %02d:%02d:%02d", clk_demo_hour, clk_demo_min, 0 );
  if( hour ) *hour= clk_demo_hour;
  if( min  ) *min = clk_demo_min;
  if( sec  ) *sec = 0;

  return true;
}

// The user can configure a round-up for the time (since the clock only shows 5 min steps).
int clk_round;

// Initializes the clock driver.
// Configures the time library for NTP servers, time zone, DST. Also records the clock rounding.
void clk_init() {
  // Default NTP poll time is SNTP_UPDATE_DELAY (sntp.c, value 3600000 ms or 1 hour).
  // Change with sntp_set_update_delay(ms)

  // Setup the servers
  configTime( cfg.getval("Timezone"), cfg.getval("NTP.server.1"), cfg.getval("NTP.server.2"), cfg.getval("NTP.server.3"));
  Serial.printf("clk : init: %s %s %s\n", cfg.getval("NTP.server.1"), cfg.getval("NTP.server.2"), cfg.getval("NTP.server.3"));
  Serial.printf("clk : timezones: %s\n", cfg.getval("Timezone") );

  // Track when time is actually set
  settimeofday_cb( [](){Serial.printf("clk : NTP sync\n");} );  // Pass lambda function to print SET when time is set

  // Disable demo
  clk_demo_mode= 0;
  
  // Setup round
  clk_round= String(cfg.getval("Round")).toInt();
  Serial.printf("clk : round: %d sec\n", clk_round );
}
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
void loop() {
  // if in config mode, do config loop (when config completes, it restarts the device)
  if( cfg.cfgmode() ) { cfg.loop(); return; }

  // In normal application mode
  wifi_check();
  but_scan();

  // If button pressed, toggle demo mode
  if( but_wentdown() ) { 
    if( clk_demo_get() ) { // Was in demo mode, switch demo off; also reset animation style
      clk_demo_set(0);
      anim_selected= anim_list[col_animation];
    } else { // Was in normal mode, switch demo on; also select animation style random
      clk_demo_set(1);
      anim_selected= anim_list[COL_ANIMATION_RANDOM];
    }
  }
  
  // Get the current time
  char buf[32];
  int curhour,curmin,cursec, avail= clk_get(&curhour,&curmin,&cursec,buf);
  if( curhour!=prevhour || curmin!=prevmin || cursec!=prevsec ) {
    // Time has changed, print to serial
    Serial.printf("clk : %s ", buf); 
    if( avail ) {
      Serial.printf("%02d:%02d ", curhour, curmin); 
      int refresh= curhour!=prevhour;
      if( col_refresh==COL_REFRESH_ONE  ) refresh|= curmin!=prevmin;
      if( col_refresh==COL_REFRESH_FIVE ) refresh|= (curmin%5==0) && (curmin!=prevmin);
      if( refresh ) {
        palette4_t * palette= col_next();
        anim_selected->start(palette,curhour%12,curmin);
      }
    } else {
      Serial.printf("[no NTP sync yet]"); 
    }
    Serial.printf("\n"); 
    prevhour=curhour; prevmin=curmin; prevsec=cursec;
  }

  // Run any pending animation
  anim_selected->step();
}

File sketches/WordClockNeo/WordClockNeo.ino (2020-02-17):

// WordClockNeo.ino - A clock that tells time, in Dutch, in steps of 5 minutes on a NeoPixel 8x8 LED matrix
//   Clock is hand-set (with flash button) and runs on ESP8266 crystal
//   It also has a demo mode: every 0.1ms the clock advances 1 minute
// Idea http://www.espruino.com/Tiny+Word+Clock
// This project https://github.com/maarten-pennings/WordClock/blob/master/README.md

#include <Adafruit_NeoPixel.h>


// The LEDs are numbered from top to bottom, from right to left (this matches the 8x8 matrix order).
// Assumption: IN side of the LED PCB is on the (top) right hand (looking to the front)
// 63 62 61 60 59 58 57 56  -  KWARTIEN
// 55 54 53 52 51 50 49 48  -  VYF*VOOR 
// 47 46 45 44 43 42 41 40  -  OVERHALF
// 39 38 37 36 35 34 33 32  -  ELFZDRIE # ZEVEN diagonal
// 31 30 29 28 27 26 25 24  -  TIENEGEN
// 23 22 21 20 19 18 17 16  -  VIERZVYF # ZES diagonal
// 15 14 13 12 11 10  9  8  -  ACHTWEEN
//  7  6  5  4  3  2  1  0  -  TWAALFSN
//                          -           # UUR missing

// All words: indexes of the LEDs that form a word (-1 terminates)
const int model_min_vijf[]    = {55,54,53,-1};
const int model_min_kwart[]   = {63,62,61,60,59,-1};
const int model_min_tien[]    = {59,58,57,56,-1};
const int model_min_voor[]    = {51,50,49,48,-1};
const int model_min_over[]    = {47,46,45,44,-1};
const int model_min_half[]    = {43,42,41,40,-1};
const int model_hour_elf[]    = {39,38,37,-1};
const int model_hour_drie[]   = {35,34,33,32,-1};
const int model_hour_zeven[]  = {36,27,18,9,0,-1};
const int model_hour_tien[]   = {31,30,29,28,-1};
const int model_hour_negen[]  = {28,27,26,25,24,-1};
const int model_hour_vier[]   = {23,22,21,20,-1}; 
const int model_hour_vijf[]   = {18,17,16,-1}; 
const int model_hour_zes[]    = {19,10,1,-1};
const int model_hour_acht[]   = {15,14,13,12,-1};
const int model_hour_twee[]   = {12,11,10,9,-1};
const int model_hour_een[]    = {10,9,8,-1};
const int model_hour_twaalf[] = {7,6,5,4,3,2,-1};
const int model_hour_empty[]  = {-1}; 


// Frame ===========================================================================================
// The frame_hours in an array for easy indexing and integer hour to an index array
// Note that 0:xx and 12:30 are supported (as well as an empty hour using 14:xx)
const int * frame_hours[] = {model_hour_twaalf,model_hour_een,model_hour_twee,model_hour_drie,model_hour_vier,model_hour_vijf,model_hour_zes,model_hour_zeven,model_hour_acht,model_hour_negen,model_hour_tien,model_hour_elf,model_hour_twaalf,model_hour_een,model_hour_empty,model_hour_empty};

// This section controls the 8x8 NeoPixel matrix

// Neopixels run at 5v0; required signal level is at 70%. 
// Since 5v0*70%=3v5 supplying 5v0 and signalling 3v3 is a border case.
// I power Neopixels from a standalone power supply.

// From https://learn.adafruit.com/adafruit-neopixel-uberguide/basic-connections
// When connecting NeoPixels live, always connect ground (–) before anything else.
// Add a large capacitor (1000 µF, 6.3V or higher) across the + and – terminals. This prevents the initial onrush of current from damaging the pixels. 
// Add a ~470 ohm resistor between MCU and data-in. This prevents spikes on the data line to damage the first pixel. 

#define FRAME_PIN_DATA   D6
#define FRAME_NUMPIXELS  64

// When we setup the NeoPixel library, we tell it how many pixels, and which pin to use to send signals.
// Note that for older NeoPixel strips you might need to change the third parameter--see the strandtest
// example for more information on possible values.
Adafruit_NeoPixel pixels = Adafruit_NeoPixel(FRAME_NUMPIXELS, FRAME_PIN_DATA, NEO_GRB + NEO_KHZ800);


void frame_init() {
    pinMode(FRAME_PIN_DATA, OUTPUT);
}

void frame_add_word(uint32_t color, const int word[] ) {
  const int * letter= word; // Point to the first NeoPixel in `word`
  while( *letter>=0 ) {
    pixels.setPixelColor(*letter,color);
    letter++; // Point to the next NeoPixel in `word`
  }
}

void frame_set_word(uint32_t color, const int word[] ) {
  pixels.clear();
  frame_add_word(color,word);
  pixels.show();
}


#define COL_MIN 0x000033
#define COL_HOUR 0x330000
#define COL_HELP 0x003300

// Sets the NeoPixels for the time specified by `hour` and `min`.
// E.g. 7:35 -> vijf over half acht
void frame_set_time(int hour, int min ) {
  pixels.clear();
  switch( min ) {
    case 0: case 1: case 2: 
      frame_add_word(0x220000,frame_hours[hour]);
      break;  
    case 3: case 4: case 5: case 6: case 7: 
      frame_add_word(COL_MIN,model_min_vijf); frame_add_word(COL_HELP,model_min_over); frame_add_word(COL_HOUR,frame_hours[hour]);
      break;  
    case 8: case 9: case 10: case 11: case 12: 
      frame_add_word(COL_MIN,model_min_tien); frame_add_word(COL_HELP,model_min_over); frame_add_word(COL_HOUR,frame_hours[hour]);
      break;  
    case 13: case 14: case 15: case 16: case 17: 
      frame_add_word(COL_MIN,model_min_kwart); frame_add_word(COL_HELP,model_min_over); frame_add_word(COL_HOUR,frame_hours[hour]);
      break;  
    case 18: case 19: case 20: case 21: case 22: 
      frame_add_word(COL_MIN,model_min_tien); frame_add_word(COL_HELP,model_min_voor); frame_add_word(COL_MIN,model_min_half); frame_add_word(COL_HOUR,frame_hours[hour+1]);
      break;  
    case 23: case 24: case 25: case 26: case 27: 
      frame_add_word(COL_MIN,model_min_vijf); frame_add_word(COL_HELP,model_min_voor); frame_add_word(COL_MIN,model_min_half); frame_add_word(COL_HOUR,frame_hours[hour+1]);
      break;  
    case 28: case 29: case 30: case 31: case 32: 
      frame_add_word(COL_MIN,model_min_half); frame_add_word(COL_HOUR,frame_hours[hour+1]);
      break;  
    case 33: case 34: case 35: case 36: case 37: 
      frame_add_word(COL_MIN,model_min_vijf); frame_add_word(COL_HELP,model_min_over); frame_add_word(COL_MIN,model_min_half); frame_add_word(COL_HOUR,frame_hours[hour+1]);
      break;  
    case 38: case 39: case 40: case 41: case 42: 
      frame_add_word(COL_MIN,model_min_tien); frame_add_word(COL_HELP,model_min_over); frame_add_word(COL_MIN,model_min_half); frame_add_word(COL_HOUR,frame_hours[hour+1]);
      break;  
    case 43: case 44: case 45: case 46: case 47: 
      frame_add_word(COL_MIN,model_min_kwart); frame_add_word(COL_HELP,model_min_voor); frame_add_word(COL_HOUR,frame_hours[hour+1]);
      break;  
    case 48: case 49: case 50: case 51: case 52: 
      frame_add_word(COL_MIN,model_min_tien); frame_add_word(COL_HELP,model_min_voor); frame_add_word(COL_HOUR,frame_hours[hour+1]);
      break;  
    case 53: case 54: case 55: case 56: case 57: 
      frame_add_word(COL_MIN,model_min_vijf); frame_add_word(COL_HELP,model_min_voor); frame_add_word(COL_HOUR,frame_hours[hour+1]);
      break;  
    case 58: case 59:  
      frame_add_word(COL_HOUR,frame_hours[hour+1]);
      break;  
  }
  pixels.show();
}
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

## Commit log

2020-02-17 improved power figures
2020-02-17 Led8x8 wiring added
2020-02-17 Added PCBs
2020-02-22 added powerarch.png
2020-02-22 power arch
2020-02-22 diode removal
2020-02-23 board mod
2020-02-23 typos and interrupt
2020-02-23 board added
2020-02-23 update schematic.jpg: added labels
2020-03-15 Version 5 of WordClockFull Added mist animation Added animation base class; animation now follows config Animations print run time Renamed (configurable) colors Added documentation comments Demo mode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
2020-03-15 User manual (power)
2020-11-22 moved power estimate
2020-11-22 8x8 led matrix image
2020-12-06 Added STLs
    [WordClockBack-v13.stl, WordClockFront-v13-box.stl, WordClockFront-v13-letters-withfront.stl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]
2021-12-01 Voltage drop measurement
